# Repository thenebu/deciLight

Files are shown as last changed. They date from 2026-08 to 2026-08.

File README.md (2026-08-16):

🇩🇪 [Deutsch](#deutsch) | 🇬🇧 [English](#english)

## Deutsch

# noiselight 🚦

Ein Echtzeit-Lärmmonitor, der den Geräuschpegel als Ampel mit RGB-LEDs anzeigt.

> ✅ **Status:** Alle unten beschriebenen Funktionen wurden auf echter Hardware getestet,
> einschließlich der Home Assistant / MQTT-Discovery-Integration und des
> browserbasierten OTA-Updates (inkl. Neustart in die neu geflashte Firmware, mehrfach
> über einen Stromzyklus hinweg bestätigt).

<details>
<summary><strong>Inhaltsverzeichnis</strong></summary>

- [📋 Funktionen](#de-funktionen)
- [🛒 Verwendete Hardware](#de-verwendete-hardware)
- [💻 Kompatible Hardware](#de-kompatible-hardware)
- [🔧 Hardware-Einrichtung](#de-hardware-einrichtung)
- [🖨️ Gehäuse (3D-Druck)](#de-gehaeuse)
- [📊 Funktionsweise](#de-funktionsweise)
- [🎚️ Konfiguration](#de-konfiguration)
- [🌐 WiFi- und Web-Konfiguration](#de-wifi-web-konfiguration)
- [🏠 MQTT- / Home-Assistant-Integration](#de-mqtt-ha)
- [🔑 Passwörter](#de-passwoerter)
- [📡 OTA-Updates (Over-the-Air)](#de-ota)
- [🚀 Bauen und Hochladen](#de-bauen-hochladen)
- [📈 Serielle Ausgabe](#de-serielle-ausgabe)
- [🔧 Kalibrierung](#de-kalibrierung)
- [🔴 Fehlerbehebung](#de-fehlerbehebung)
- [📚 Referenzen](#de-referenzen)
- [📝 Lizenz](#de-lizenz)

</details>

## 📋 Funktionen

- **Echtzeit-Geräuscherkennung** über ein I2S-MEMS-Mikrofon
- **3-farbige Ampelanzeige**:
  - 🟢 **GRÜN** – Geräusch ist leise (unter dem Schwellenwert)
  - 🟡 **GELB** – Geräusch ist moderat (im mittleren Bereich)
  - 🔴 **ROT** – Geräusch ist laut (über dem Schwellenwert)
- **7er-NeoPixel-RGB-LED-Streifen** für helle, gut sichtbare Rückmeldung
- **A-bewertete Schallpegelmessung** (dBA) für eine realistische Wahrnehmung
- **Konfigurierbare Schwellenwerte** über persistenten Speicher
- **WiFi-Client-Modus** mit automatischem AP-Fallback für die Ersteinrichtung
- **Babyphone-Modus** – warmes, dimmbares Nachtlicht am Gerät, während ein anhaltend
  lauter Pegel (Auslöseschwelle + Halte-/Löschzeit mit Hysterese) einen Alarm
  ausschließlich per MQTT an Home Assistant meldet; die LED selbst bleibt ruhig
- **Live-Hören** – 16-kHz-PCM-Audiostream direkt im Browser, eigener TCP-Port, eigenes
  Passwort, mit Auto-Gain, damit auch leise Geräusche hörbar sind
- **MQTT- / Home-Assistant-Integration** mit MQTT-Discovery
- **Over-the-Air (OTA) Firmware-Updates**, sobald das Gerät mit dem Heimnetzwerk verbunden ist — per PlatformIO/ArduinoOTA **oder** direkt per Datei-Upload im Web-UI, ganz ohne Entwicklungsumgebung
- **Konfigurations-Export/Import** zum Sichern oder Klonen der Geräteeinstellungen
- **5-Minuten-Verlaufsdiagramm** im Web-UI
- **Firmware-Version** sichtbar im Web-UI-Footer und über MQTT (Diagnose-Topic mit Uptime, freiem Speicher, WLAN-Signalstärke, IP-Adresse und letztem Reset-Grund)
- **"Letzter Alarm"-Zeitstempel** über MQTT (Home-Assistant-Timestamp-Entity, zeigt automatisch "vor X Minuten" an)
- **Zwei getrennte Passwörter** – eins fürs Firmware-Flashen, eins fürs Live-Hören, damit
  das Weitergeben des einen nicht das andere mit verschenkt

## 🛒 Verwendete Hardware

Diese Teile habe ich selbst gekauft (Amazon.de, Stand: wie unten verlinkt):

| Komponente | Preis | Hinweis | Link |
|---|---|---|---|
| LED | 18€ (5er-Pack, 3,60€/Stk.) | WS2812 RGB-LED-Ring, 7×5050 mit integrierten Treibern | [Amazon](https://www.amazon.de/dp/B09K57Y9FL?ref=ppx_yo2ov_dt_b_fed_asin_title) |
| Board | 20€ (2er-Pack, 10,00€/Stk.) | Waveshare ESP32-S3 Mini Development Board | [Amazon](https://www.amazon.de/dp/B0CSK8B4GS?ref=ppx_yo2ov_dt_b_fed_asin_title) |
| Mikrofon | 9€ (3er-Pack, 3,00€/Stk.) | INMP441 omnidirektionales Mikrofonmodul, 24-Bit I2S | [Amazon](https://www.amazon.de/dp/B0DX1VMRK1?ref_=ppx_hzsearch_conn_dt_b_fed_asin_title_2) |

Grobe Gesamtkosten für **ein** komplettes Gerät (je ein LED-Ring + Board + Mikrofon):
3,60€ + 10€ + 3€ ≈ **16,60€ pro Gerät**.

Da alle drei Teile im Mehrfach-Pack verkauft werden, lassen sich mit den übrigen Teilen
mehrere weitere Geräte bauen, ohne viel mehr als für ein einzelnes zu bezahlen. Preise
und Verfügbarkeit entsprechen dem Stand, als die Links hinzugefügt wurden, und können
sich ändern. Die Links sind normale Amazon-Links (kein Affiliate-Tracking durch dieses
Projekt) — einfach das, was ich selbst gekauft habe.

## 💻 Kompatible Hardware

Dieses Projekt ist auf **ESP32** zugeschnitten — nicht auf ESP8266 oder andere
Mikrocontroller. Es nutzt ESP32-spezifische Peripherie (I2S für das Mikrofon, RMT für
die WS2812-LEDs) sowie FreeRTOS-Multitasking über zwei Kerne. Mindestanforderungen an
ein Ersatz-/Alternativboard:

- **Chip:** ESP32 (Xtensa- oder RISC-V-Varianten wie S3/C3) mit I2S- und
  RMT-Peripherie. Getestet auf **ESP32-S3**; andere ESP32-Varianten mit passender
  Pinbelegung sollten ebenfalls funktionieren, sind aber ungetestet.
- **Flash:** mindestens **4 MB**. Die OTA-Partitionstabelle (`default.csv`) braucht
  zwei App-Partitionen à ~1,25 MB für abwechselndes Flashen — die aktuelle Firmware
  belegt davon bereits ~86 % einer Partition, kleinere Flash-Größen reichen nicht.
- **RAM:** die üblichen ~320 KB internes SRAM eines ESP32(-S3) reichen locker (aktuell
  ~31 % Auslastung zur Laufzeit); **PSRAM wird nicht benötigt**.
- **WLAN:** 2,4-GHz-WiFi (Pflicht für Web-UI, MQTT und OTA).
- **USB:** Natives USB-CDC (wie beim ESP32-S3) vereinfacht Flashen und seriellen
  Monitor erheblich, ist aber kein Hard-Requirement — ein Board mit klassischer
  USB-UART-Brücke funktioniert auch, dann greift aber die Log-Umleitung in
  `include/config.h` nicht (die ist speziell für Boards ohne UART-Brücke gedacht,
  siehe Kommentar dort).

**Nicht kompatibel:** ESP8266 (kein I2S/RMT, kein FreeRTOS-Multicore, andere
Partitionierung) sowie generische AVR-/STM32-Boards ohne ESP-IDF-Unterstützung.

## 🔧 Hardware-Einrichtung

### Pin-Konfiguration

| Komponente | Pin | Farbe | Beschreibung |
|---|-----|---|---|
| **WS2812 LED-Daten** | GPIO 1 | - | NeoPixel-Streifen (7 LEDs) |
| **I2S L/R Select** | GPIO 3 | Grün | Mikrofon-Kanalauswahl (HIGH = RECHTER Kanal) |
| **I2S Word Select** | GPIO 4 | Blau | Mikrofon L/R-Takt |
| **I2S Serial Clock** | GPIO 5 | Weiß | Mikrofon-Bittakt |
| **I2S Serial Data** | GPIO 2 | Gelb | Mikrofon-Audiodaten |
| **Modus-Taster** | GPIO 6 | - | Taster gegen GND (interner Pull-up, aktiv LOW) |
| **Stromversorgung (5V)** | 5V | - | USB-Netzteil |
| **GND** | GND | - | Masse |

### Modus-Taster

Ein optionaler Taster an GPIO 6 (gegen GND) erlaubt Bedienung ohne WebUI:

- **Kurzer Druck**: schaltet den Anzeigemodus weiter (Ampel → VU-Meter → Babyphone →
  Einfarbig → Ampel …)
- **Langer Druck (gehalten, >600 ms)**: rampt die LED-Helligkeit hoch/runter; an den
  Grenzen (0/255) dreht die Richtung automatisch um (Ping-Pong). Beim Loslassen wird
  der erreichte Wert dauerhaft gespeichert.

Ist kein Taster angeschlossen, bleibt GPIO 6 dank internem Pull-up dauerhaft HIGH und
es passiert nichts - die Funktion ist also optional und stört ohne Hardware nicht.

## 🖨️ Gehäuse (3D-Druck)

Die 3D-Druckdateien liegen in [`3dprinting/`](./3dprinting) (Fusion-360-Quelldatei
sowie fertige `.3mf`-Projekte für Base, Cover, Visor, LED-Mount, ESP-Mount, Standfüße,
Linse und Reflektor). Details zu Druckprofilen findest du in
[`3dprinting/README.md`](./3dprinting/README.md).

In der Praxis gedruckt: die **Linse** in **PETG, transluzent**, damit das Licht schön
diffus streut - der Rest des Gehäuses (Base, Cover, Visor, LED-Mount, ESP-Mount,
Standfüße) in **PLA**. Das weicht vom in `3dprinting/README.md` hinterlegten
Bambu-Studio-Profil ab (dort ist z. B. PETG/TPU für die übrigen Teile vorgesehen) -
PLA hat sich für den Innenausbau als völlig ausreichend erwiesen, da das Gehäuse keiner
Wärme- oder mechanischen Belastung ausgesetzt ist.

## 📊 Funktionsweise

### Audio-Verarbeitungspipeline

1. **I2S-Abtastung** (48 kHz, 32-Bit)
   - Erfasst kontinuierlich Audio vom Mikrofon
   - Hochpräzise digitale Abtastung

2. **IIR-Filterung**
   - **Equalizer-Filter** (INMP441): Glättet den Frequenzgang des Mikrofons
   - **A-Bewertungsfilter**: Bildet die Empfindlichkeit des menschlichen Ohrs nach
     (betont mittlere Frequenzen)

3. **Schallpegelberechnung**
   - Wandelt gefilterte Samples in dB (Dezibel) um
   - Nutzt die Mikrofonkalibrierung aus `MIC_REF_DB`/`MIC_SENSITIVITY`
   - **Messfenster: 125 ms** (`SAMPLES_SHORT` = 6000 Samples bei 48 kHz). Das ist
     exakt die Zeitbewertung **"FAST" nach IEC 61672**, die auch jeder handelsübliche
     Schallpegelmesser verwendet — deshalb ist der Wert nicht frei wählbar, ohne die
     Kalibrierung zu entwerten
   - Gelesen wird allerdings in **zwei 62,5-ms-Halbblöcken** (`SAMPLES_CHUNK`), deren
     Quadratsummen addiert werden, bevor ein Messwert entsteht. Die IIR-Filter tragen
     ihren Zustand über den Aufruf hinaus, das Ergebnis ist also bitgleich zu einem
     durchgehenden 125-ms-Block — halbiert aber den Sample-Puffer von 24 KB auf 12 KB
   - Anschließend exponentielle Glättung (α = 0,3 pro Fenster, Zeitkonstante ≈ 350 ms)

4. **Entscheidungslogik**
   ```
   if (dB < db_normal_switchover)      → GRÜN   (ruhig)
   if (dB < db_warning_switchover)     → GELB   (laut)
   sonst                               → ROT    (zu laut)
   ```

## 🎚️ Konfiguration

### Standardwerte

Alle in `include/config.h`, zur Laufzeit über das Web-UI änderbar und im NVS persistent:

```cpp
DB_FLOOR                   37.0   // Grundpegel (unteres Ende der VU-Skala)
DB_NORMAL_SWITCHOVER       50.0   // darunter GRÜN, darüber GELB
DB_WARNING_SWITCHOVER      65.0   // darunter GELB, darüber ROT
LED_BRIGHTNESS               25   // 0-255
DISPLAY_MODE                  1   // 0=Ampel, 1=VU-Meter, 2=Babyphone

BABYPHONE_TRIGGER_DB       65.0   // Schwelle, die anhaltend überschritten werden muss
BABYPHONE_SUSTAIN_MS       5000   // so lange darüber → Alarm
BABYPHONE_CLEAR_MS         3000   // so lange darunter → Alarm gelöscht
BABYPHONE_NIGHT_COLOR  0xFF3C00   // warmes Bernstein, fast ohne Blauanteil
BABYPHONE_NIGHT_BRIGHTNESS   15   // 0-255, gedimmt
```

### Empfohlene Einstellungen

| Umgebung | Grün→Gelb | Gelb→Rot | Hinweise |
|---|---|---|---|
| Bibliothek/Ruhig | 30 | 50 | Sehr leise Räume |
| Klassenzimmer | 40 | 60 | Normaler Unterricht |
| Aktives Klassenzimmer | 45 | 70 | Gruppenarbeitsphasen |
| Werkstatt | 60 | 80 | Toleriert Maschinenlärm |
| Kinderzimmer (Babyphone) | 45 | 65 | Auslöseschwelle separat einstellen |

### Wissenschaftliche Grundlage der Standardwerte

Die Werkseinstellungen (Grün→Gelb bei **50 dB**, Gelb→Rot bei **65 dB**) sind keine
Zufallszahlen, sondern orientieren sich an anerkannten Lärmwirkungs-Richtwerten:

- **50 dB (Grün→Gelb):** Die WHO nennt in den *Guidelines for Community Noise* (1999,
  Tabelle 4.1) 50 dB LAeq als Richtwert, ab dem in Wohn-/Aufenthaltsräumen mit
  **moderater Belästigung** zu rechnen ist ("outdoor living area", moderate annoyance).
  Oberhalb dieses Pegels beginnt Lärm subjektiv als störend wahrgenommen zu werden.
- **65 dB (Gelb→Rot):** Normale Unterhaltungssprache liegt laut NIDCD/CDC-Referenztabellen
  bei etwa 60–70 dB(A) (1 m Abstand). Die WHO-Richtlinie weist darauf hin, dass oberhalb
  eines Hintergrundpegels von rund 65 dB die Sprachverständlichkeit deutlich leidet und
  die Stimme angehoben werden muss, während gleichzeitig laut Tabelle 4.1 die Schwelle zur
  **ernsten Belästigung** ("serious annoyance") erreicht wird.
- Zum Einordnen: **Gehörschäden** durch Dauerlärm sind erst bei deutlich höheren Pegeln
  relevant — NIOSH empfiehlt max. 85 dB(A) über 8 Std. (REL), OSHA erlaubt gesetzlich
  max. 90 dB(A) über 8 Std. (PEL). ROT markiert hier also eine **Komfort-/Konzentrations-
  Warnschwelle**, nicht bereits eine Gehörschäden-Warnung — dafür liegen die Pegel weit
  genug auseinander, dass ROT als früher, harmloser Hinweis taugt.
- Für spezielle Umgebungen (Klassenzimmer, Kinderzimmer) empfiehlt die WHO strengere
  Innenraum-Richtwerte (z. B. 35 dB LAeq in Klassenzimmern zur Sprachverständlichkeit,
  30 dB LAeq nachts im Schlafzimmer) — diese liegen jedoch so nah am technischen
  Grundrauschen des Mikrofons (`DB_FLOOR` ≈ 37 dB), dass eine LED-Ampel bei diesen engen
  Werten kaum noch sinnvoll zwischen "Grün" und "Gelb" unterscheiden könnte. Die
  Empfehlungen in der Tabelle oben sind deshalb praxisnah nach oben verschobene
  Näherungswerte, keine 1:1-Übernahme der WHO-Innenraumwerte.

**Quellen:**
- WHO (1999): [*Guidelines for Community Noise*](https://www.who.int/publications/i/item/a68672), Tabelle 4.1 (Richtwerte für spezifische Umgebungen)
- WHO Regional Office for Europe (2018): [*Environmental Noise Guidelines for the European Region*](https://cdn.who.int/media/docs/default-source/who-compendium-on-health-and-environment/who_compendium_noise_01042022.pdf)
- NIOSH: [*Criteria for a Recommended Standard – Occupational Noise Exposure*](https://www.nonoise.org/hearing/criteria/criteria.htm) (REL 85 dB(A)/8h)
- OSHA: [*Occupational Noise Exposure*](https://www.osha.gov/noise) (PEL 90 dB(A)/8h)

## 🌐 WiFi- und Web-Konfiguration

### WiFi-Modi

Das Gerät verbindet sich mit deinem Heimnetzwerk als **WiFi-Client (STA)**. Falls beim
Start noch kein Netzwerk konfiguriert ist oder das konfigurierte Netzwerk nicht
erreichbar ist, fällt es auf seinen eigenen **Access Point (AP)** zurück, sodass du das
Web-UI immer erreichen kannst:

- **SSID (Netzwerkname):** `noiselight`
- **Passwort:** `12345678`
- **IP-Adresse:** `192.168.4.1`
- **Port:** `80` (HTTP)

Sobald das Gerät mit dem Heimnetzwerk verbunden ist, ist es außerdem per mDNS unter
**`http://noiselight.local`** erreichbar.

### Erststart-WiFi über .env (optional)

Falls dein Smartphone/Laptop den `noiselight`-AP nicht sehen oder nicht beitreten kann,
oder du diesen Schritt lieber ganz überspringen möchtest, kopiere `.env.example` nach
`.env` (in .gitignore, wird nie committet) und trage deine Heim-WiFi-Zugangsdaten ein:

```bash
cp .env.example .env
# edit .env: WIFI_SSID=..., WIFI_PASSWORD=...
platformio run -t upload -e esp32-s3-devkitc1-n4r2
```

`load_env.py` bettet diese Werte als NVS-Standard ein, den ein frisch geflashtes Gerät
bei seinem allerersten Start verwendet — das ist nur relevant, bis die WiFi-Einstellungen
des Geräts einmal über das Web-UI gespeichert wurden (oder bereits aus einem früheren
Flash-Vorgang im NVS vorhanden sind); danach gewinnt immer der im NVS gespeicherte Wert
gegenüber dem `.env`-Standard.

### Einrichtungsschritte

1. **Erstverbindung (AP-Fallback):**
   - Öffne die WiFi-Einstellungen deines Geräts (Smartphone, Tablet, Laptop)
   - Wähle das Netzwerk `noiselight`
   - Gib das Passwort ein: `12345678`

2. **Konfigurationsseite öffnen:**
   - Öffne einen Browser und gehe zu: `http://192.168.4.1`
   - Das Web-Interface lädt automatisch

3. **Heim-WiFi beitreten:**
   - Trage SSID/Passwort deines Netzwerks im Bereich **Network** des Web-UI ein und
     speichere
   - Das Gerät verbindet sich mit deinen Zugangsdaten neu; bei Erfolg beendet es den AP
     und ist fortan unter `http://noiselight.local` (oder seiner neuen DHCP-Adresse)
     erreichbar
   - Schlägt die Verbindung fehl, fällt das Gerät wieder in den AP-Modus zurück, sodass
     du nie ausgesperrt wirst

4. **Einstellungen in Echtzeit konfigurieren:**
   - Live-dB-Pegelanzeige aktualisiert sich alle 200 ms
   - Alle Schieberegler aktualisieren die Vorschau sofort
   - Drücke **Save Configuration**, um die Einstellungen im Gerätespeicher zu sichern

### Web-Interface-Funktionen

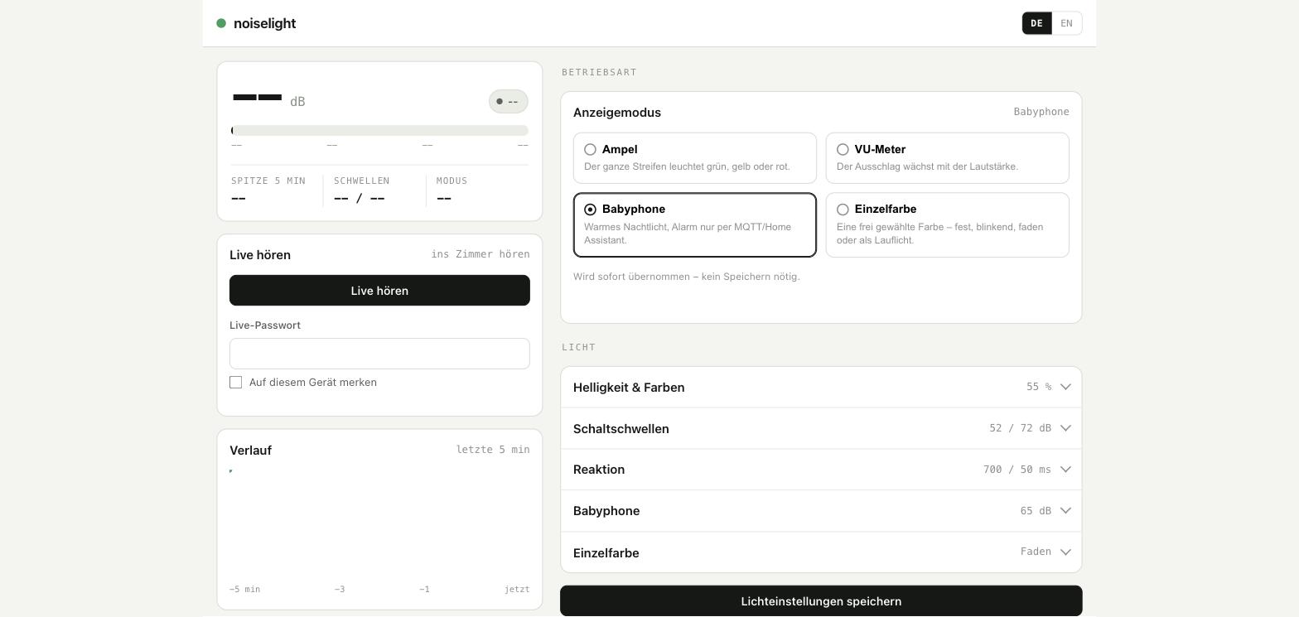
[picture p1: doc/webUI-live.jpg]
noiselight Web Interface – Live-Pegel, Betriebsart und Lichteinstellungen

*Live-dB-Anzeige, Verlaufsgraph und Betriebsart-Auswahl (Ampel / VU-Meter / Babyphone / Einzelfarbe)*

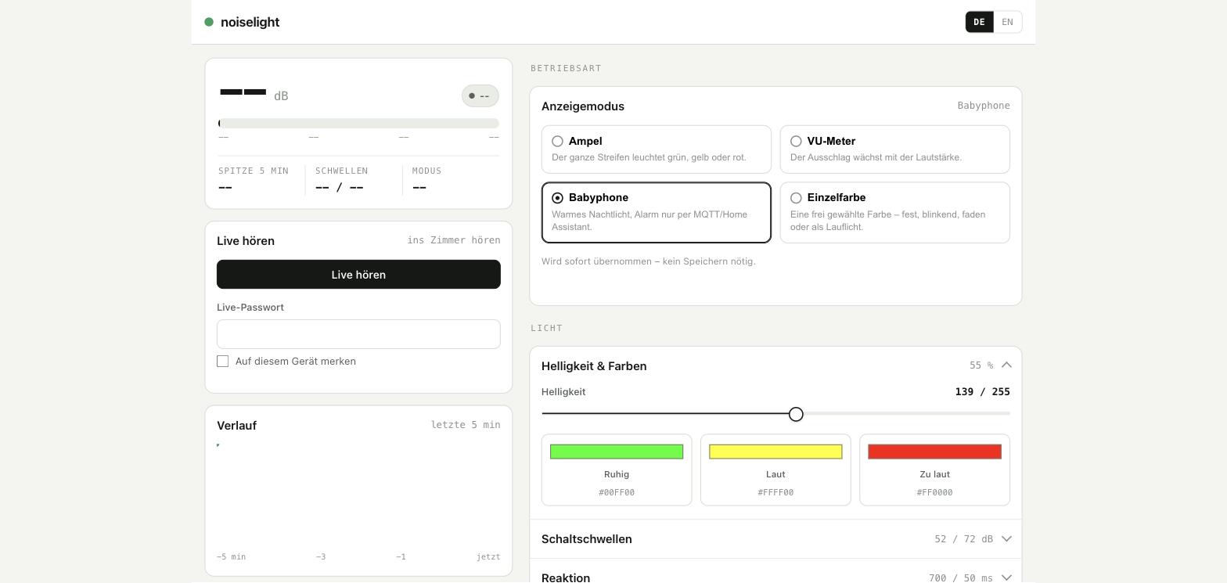
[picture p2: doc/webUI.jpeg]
noiselight Web Interface – Helligkeit & Farben

*Ausgeklappte Lichteinstellungen: Helligkeit sowie Farben für Ruhig/Laut/Zu laut*

**Anzeigemodus**
- **Ampel:** Alle LEDs zeigen eine einzelne Farbe (GRÜN/GELB/ROT)
- **VU-Meter:** LEDs bilden einen Verlaufsbalken, der die Geräuschintensität zeigt
- **Babyphone:** Der Streifen ist ein statisches, warmes Nachtlicht und reagiert
  bewusst *nicht* auf Geräusche. Der Alarm läuft ausschließlich über MQTT — die
  Beleuchtung im Kinderzimmer soll nicht blinken, wenn das Kind weint

**Live hören**
- Eigene Karte direkt unter der Pegelanzeige, in **jedem** Anzeigemodus verfügbar
- Streamt 16-kHz-PCM-Mono über einen eigenen TCP-Port (8081, `AUDIO_STREAM_PORT`) und
  spielt es über die Web-Audio-API im Browser ab
- Geschützt durch `LIVE_PASSWORD` — nicht durch das OTA-Passwort (siehe
  **Passwörter** weiter unten). Optional per Häkchen im Browser merkbar
- Ein Auto-Gain skaliert jeden Block auf einen Zielpegel (Attack sofort, Release
  verzögert), weil das Mikrofon für *Messgenauigkeit* kalibriert ist und ein leises
  Wimmern sonst kaum hörbar wäre
- Jeweils nur ein Zuhörer gleichzeitig; ein zweiter Verbindungsversuch wird mit
  "503 stream busy" abgewiesen. Der Ringpuffer wird erst beim Verbinden alloziert
  und beim Trennen wieder freigegeben

**LED-Einstellungen**
- **Helligkeit:** 0–255 (Standard: 25)
- **Farbauswahl:** Individuelle Farben für jede Lärmstufe wählen

**Umschaltpunkte (dB)**
- **Grundpegel:** Geräusch-Grundpegel (Standard: 37 dB)
- **Grün→Gelb:** Übergangsschwelle (Standard: 50 dB)
- **Gelb→Rot:** Alarmschwelle (Standard: 65 dB)
- **Farbvorschau:** Visueller Balken zeigt LED-Farben über den dB-Bereich

**Reaktionszeiten**
- **Nachleuchten:** Wie lange die aktuelle Farbe gehalten wird, nachdem der Ton
  aufgehört hat (0–3000 ms, Standard: 1500 ms)
- **Ansprechzeit:** Minimales Aktualisierungsintervall zwischen LED-Wechseln
  (0–500 ms, Standard: 100 ms). Gilt für Ampel *und* VU-Meter; letzteres hat
  zusätzlich eine harte Untergrenze von 20 ms, weil ein WS2812-Streifen darüber
  hinaus ohnehin nicht sinnvoll aktualisiert werden kann

**Babyphone-Einstellungen**
- **Auslöseschwelle** (dB), **Anhaltend für** (s) und **Löscht nach** (s) bilden einen
  Zustandsautomaten mit asymmetrischer Hysterese: der Alarm feuert erst nach einer
  ununterbrochen lauten Phase und löscht sich erst nach einer ununterbrochen leisen —
  ein kurzes Luftholen zwischen zwei Schreien setzt also nichts zurück
- **Nachtlicht-Farbe** und **-Helligkeit** für den Streifen in diesem Modus

**Verlaufsdiagramm**
- Live-Liniendiagramm der letzten 5 Minuten der dB-Messwerte (1 Sample/Sek.), bereitgestellt
  über `/api/history`

**Tagesstatistik (tägliche Zeitverteilung)**
- Gestapeltes Balkendiagramm, das zeigt, wie viel Zeit jeder Stunde (heute, 24 Buckets)
  in welchem Farbzustand (NORMAL/WARNING/ALERT) verbracht wurde, bereitgestellt über
  `/api/hourly`
- Setzt sich automatisch um Mitternacht (Ortszeit) zurück; ein **Zurücksetzen**-Button
  löscht sie auch manuell über `/api/hourly/reset`
- Erfordert, dass die Uhr des Geräts zuerst per NTP synchronisiert wurde (siehe
  **Zeitzone** unten) — bis dahin zeigt das Diagramm einen Hinweis statt Daten
- Die Einteilung in Buckets basiert auf der rohen (nicht gedämpften) Geräuschklassifizierung
  bei jedem Loop-Tick — derselben Klassifizierung, die MQTT als "level"-Sensor
  veröffentlicht — und nicht auf der anzeigegeglätteten Farbe, die ruhige Phasen
  unterbewerten würde

**Zeitzone**
- Der Bereich **Network** enthält ein Feld **Zeitzone (POSIX TZ)**, z. B.
  `CET-1CEST,M3.5.0,M10.5.0/3` (Europe/Berlin, Standard) oder `EST5EDT,M3.2.0,M11.1.0`
  (US-Ostküste) — wird direkt an die `configTzTime()`-Funktion des ESP32 übergeben,
  sodass die Stunden-Buckets der Tagesstatistik mit deiner lokalen Uhrzeit
  übereinstimmen, inklusive Sommerzeitumstellung
- Anders als ein fester UTC-Offset kodiert ein POSIX-TZ-String auch, *wann* sich die
  Uhr verschiebt (der Teil `M3.5.0,M10.5.0/3`), sodass Sommer-/Winterzeit automatisch
  gehandhabt wird — keine manuelle Anpassung zweimal im Jahr nötig
- Erfordert eine Internetverbindung (NTP-Sync gegen `pool.ntp.org`/`time.nist.gov`);
  greift nicht im AP-Fallback-Modus ohne Internetzugang

### Persistenter Speicher

Alle Konfigurationsänderungen werden automatisch im **NVS (Non-Volatile Storage)** des
ESP32 gespeichert:
- Einstellungen überstehen einen Stromausfall
- Werden beim Gerätestart automatisch geladen
- Konfiguration erreichbar über `/api/config`, WiFi-/MQTT-Einstellungen über
  `/api/network`

### Konfigurations-Export/Import

Das Web-UI kann die gesamte Gerätekonfiguration (LED-/Schwellenwert-Einstellungen
**und** WiFi-/MQTT-Zugangsdaten) als JSON-Datei über `/api/config/export` exportieren
und über `/api/config/import` auf einem anderen Gerät (oder nach einem Reset)
wiederherstellen. Praktisch, um eine funktionierende Einrichtung zu sichern oder auf
ein zweites Gerät zu klonen.

> ⚠️ Die exportierte Datei enthält deine WiFi- und MQTT-Passwörter im Klartext —
> behandle sie wie jede andere Zugangsdatendatei.

## 🏠 MQTT- / Home-Assistant-Integration

Sobald das Gerät mit dem Heimnetzwerk verbunden ist, kann es seine Lärmmesswerte an
einen MQTT-Broker senden und sich selbst über MQTT-Discovery bei **Home Assistant**
anmelden — keine manuelle Entitätskonfiguration nötig.

### Einrichtung

1. Trage im Bereich **Network** des Web-UI Host/Port deines MQTT-Brokers ein sowie,
   falls erforderlich, Benutzername/Passwort, und speichere.
2. Das Gerät verbindet sich automatisch und meldet sich per Discovery unter
   `homeassistant/<component>/<device-id>/...` an. Auf dem schnellen State-Topic
   (alle ~2 Sekunden, `noiselight/<device-id>/state`):
   - **Noise Level** – der aktuelle dB-Messwert, auf eine ganze Zahl gerundet
   - **Noise Level Status** – `normal` / `warning` / `alert`
   - **Anzeigemodus** – `traffic_light` / `vu_meter` / `babyphone`
   - **Babyphone Alarm** – `binary_sensor` (`device_class: sound`), spiegelt den
     Zustandsautomaten aus dem Babyphone-Modus. Bewusst auf dem 2-Sekunden-Topic und
     nicht bei der Diagnose, damit ein Alarm schnell in HA ankommt
3. Ein Verfügbarkeits-Topic (`.../availability`) sorgt dafür, dass Home Assistant das
   Gerät als offline markiert, wenn die Verbindung abbricht.
4. Ein Diagnose-Topic (`noiselight/<device-id>/debug`, alle 60 Sekunden) liefert als
   eigene "diagnostic"-Entitäten:
   - **Firmware Version**, **Uptime**, **WiFi Signal**, **IP Address**,
     **Last Reset Reason**
   - **Free Heap** – Summe *aller* freien Bytes
   - **Largest Free Block** – größter *zusammenhängender* Block. Zusammen mit Free Heap
     auf einer Karte macht das Fragmentierung sichtbar: bleibt Free Heap flach, während
     dieser Wert über Tage absackt, stanzt irgendwo eine malloc/free-Schleife Löcher in
     den Heap
   - **Letzter Alarm (Rot)** – Zeitstempel-Sensor, der automatisch anzeigt, wie lange
     der letzte Alarm-Zustand her ist

Die Geräte-ID wird aus den letzten 6 Hex-Ziffern der MAC-Adresse abgeleitet (z. B.
`noiselight-a1b2c3`).

## 🔑 Passwörter

Die Firmware kennt **zwei getrennte Zugangsdaten** (beide in `include/config.h`):

| Define | Standard | Schützt |
|---|---|---|
| `OTA_PASSWORD` | `changeme-ota` | ArduinoOTA (Flashen per PlatformIO/IDE) **und** `POST /update` im Web-UI |
| `LIVE_PASSWORD` | `changeme-live` | Live-Hören auf Port 8081 (`/listen`) |

Dazu `OTA_USERNAME` und `LIVE_USERNAME` (beide `admin`) für die HTTP-Basic-Auth der
zwei Endpunkte; ArduinoOTA selbst prüft nur das Passwort.

Warum getrennt: Firmware flashen kann das Gerät unbrauchbar machen und sollte bei dem
bleiben, der es wartet. Ins Zimmer hören ist dagegen eine Alltagshandlung für alle im
Haushalt — und die, die man um drei Uhr nachts halbwach auf dem Handy eintippt. Das
Live-Passwort weiterzugeben darf nicht bedeuten, das Recht zum Neuflashen mitzuverschenken.

> ⚠️ **Beide Standardwerte vor dem Einsatz im Heimnetz ändern.** Sie stehen im Klartext
> in diesem öffentlichen Repository.

Nur das Live-Passwort lässt sich im Browser per Häkchen "Auf diesem Gerät merken"
speichern (`localStorage`, im Klartext, gebunden an die Adresse des Geräts). Für das
OTA-Passwort gibt es diese Option bewusst nicht.

> **Hinweis:** Das Web-UI baut seine `Authorization`-Header in JavaScript, und dieser
> Code ist ein String-Literal in `src/web.cpp` — er sieht die `#define`s nicht. Die
> *Benutzernamen* stehen dort ein zweites Mal. Änderst du einen davon, musst du ihn an
> beiden Stellen ändern.

## 📡 OTA-Updates (Over-the-Air)

Sobald das Gerät mit deinem Heimnetzwerk verbunden ist (STA-Modus), kann die Firmware
statt per USB über WiFi aktualisiert werden — mit der dedizierten
`esp32-s3-devkitc1-n4r2-ota`-PlatformIO-Umgebung:

```bash
platformio run -t upload -e esp32-s3-devkitc1-n4r2-ota
```

Dies lädt auf `noiselight.local` hoch und benötigt das in `include/config.h`
konfigurierte OTA-Passwort (`OTA_PASSWORD`, muss mit `upload_flags` in
`platformio.ini` übereinstimmen). **Ändere das Standardpasswort, bevor du das Gerät in
deinem Heimnetzwerk einsetzt** — sonst kann jeder im selben Netzwerk einen
OTA-Flash-Versuch starten. OTA ist erst nach einer erfolgreichen WiFi-STA-Verbindung
aktiviert; im AP-Fallback-Modus ist es nie erreichbar.

> **Toolchain-Hinweis:** `platformio.ini` pinnt die `espressif32`-Platform auf den
> [pioarduino](https://github.com/pioarduino/platform-espressif32)-Fork (Arduino-ESP32
> 3.3.11 / ESP-IDF 5.5.5) — bewusst dieselbe Core-Generation wie die Arduino-IDE-
> Installation. Der ESP32-S3-Bootloader hat App-Rollback aktiviert: ein per OTA
> geschriebenes Image muss vom selben Core-Generation stammen wie der Bootloader,
> sonst validiert das Image nicht und der Bootloader fällt beim nächsten Neustart
> stillschweigend auf die alte Partition zurück, ohne die neue Firmware auch nur
> einmal zu starten. Mit gepinntem `pioarduino` und einer Selbstbestätigung beim Boot
> (`esp_ota_mark_app_valid_cancel_rollback()` in `src/main.cpp`, sobald die laufende
> Partition auf "pending verify" steht) funktioniert OTA jetzt zuverlässig — mehrfach
> über einen echten Stromzyklus hinweg getestet.

**Browserbasiertes Hochladen:** Das WebUI hat außerdem einen eigenen Bereich
"Firmware-Update" zum direkten Hochladen einer `.bin`-Datei aus einem Browser-Tab,
ohne PlatformIO oder Arduino IDE. Der `/update`-Endpoint ist per HTTP Basic Auth
geschützt — Benutzername `admin` (`OTA_USERNAME`), Passwort `OTA_PASSWORD` (beide in
`include/config.h`). Trägst du im WebUI-Passwortfeld das richtige `OTA_PASSWORD` ein,
läuft der Upload direkt durch; rufst du `/update` ohne diese Zugangsdaten auf (oder ist
das Feld leer/falsch), fragt stattdessen der Browser selbst mit einem Login-Popup nach
Benutzername/Passwort. Fertige Binärdateien für diesen Weg liegen im Verzeichnis
[`firmware/`](firmware/) — eine `.bin` pro `FIRMWARE_VERSION`, automatisch von jedem
`pio run` gebaut.

## 🚀 Bauen und Hochladen

### Voraussetzungen

- PlatformIO (VS-Code-Erweiterung oder CLI)
- Arduino IDE (optional, für direkte Kompilierung)

### Build

```bash
# Using PlatformIO
platformio run -e esp32-s3-devkitc1-n4r2

# Or in VS Code: Ctrl+Shift+B → Build
```

### Upload

```bash
# Using PlatformIO (USB)
platformio run -t upload -e esp32-s3-devkitc1-n4r2

# Or over WiFi, once on your home network (see OTA section above)
platformio run -t upload -e esp32-s3-devkitc1-n4r2-ota

# Or in VS Code: Ctrl+Shift+B → Upload
```

## 📈 Serielle Ausgabe

Das Gerät gibt dB-Messwerte über den seriellen Monitor aus (115200 Baud):

```
Leq: 45.3 dB | Min: 40 | Max: 60 | GREEN
Leq: 62.1 dB | Min: 40 | Max: 60 | RED
Leq: 55.2 dB | Min: 40 | Max: 60 | YELLOW
```

## 🔧 Kalibrierung

### Mikrofonempfindlichkeit

Wenn die Messwerte durchgehend abweichen:

1. **Bekannten Schallpegel messen** (z. B. mit einer Smartphone-App)
2. **Mit der seriellen Ausgabe vergleichen**
3. **MIC_OFFSET_DB in `main.cpp` anpassen:**
   ```cpp
   #define MIC_OFFSET_DB 3.0103  // Increase/decrease calibration offset
   ```

## 🔴 Fehlerbehebung

| Problem | Ursache | Lösung |
|---|---|---|
| Immer GRÜN | Mikrofon nicht angeschlossen | I2S-Pins prüfen (GPIO 3, 5, 2) |
| Immer ROT | Kalibrierung falsch | MIC_OFFSET_DB anpassen |
| Keine serielle Ausgabe | Falsche Baudrate | Auf 115200 einstellen |
| Keine LED-Reaktion | Falscher LED-Pin | GPIO-1-Verbindung prüfen |
| Hoher Grundgeräuschpegel des Mikrofons | Elektrisches Rauschen | Datenleitungen abschirmen, Stromversorgung prüfen |
| Gerät bleibt am `noiselight`-AP hängen | Heim-WiFi nicht erreichbar/falsches Passwort | Zugangsdaten im Web-UI prüfen oder erneut mit dem AP verbinden und neu eingeben |
| MQTT-Entitäten erscheinen nicht in Home Assistant | Broker nicht erreichbar oder Discovery noch nicht gesendet | Host/Port/Zugangsdaten in den Netzwerkeinstellungen prüfen; Discovery wird bei jeder Neuverbindung erneut gesendet |
| OTA-Upload schlägt fehl/läuft in Timeout | Gerät im AP-Fallback oder falsches `--auth`-Passwort | Sicherstellen, dass das Gerät im Heimnetzwerk ist (`noiselight.local` löst auf) und `OTA_PASSWORD` mit `platformio.ini` übereinstimmt |

## 📚 Referenzen

- **Original deciLight Project**: https://github.com/bbbenji/deciLight
- **FastLED Documentation**: http://fastled.io/
- **ESP-IDF I2S API**: https://docs.espressif.com/projects/esp-idf/en/latest/esp32/api-reference/peripherals/i2s.html
- **A-weighting Filter**: https://en.wikipedia.org/wiki/A-weighting
- **PubSubClient (MQTT)**: https://github.com/knolleary/pubsubclient
- **Home Assistant MQTT Discovery**: https://www.home-assistant.io/integrations/mqtt/#mqtt-discovery

## 📝 Lizenz

Dieses Projekt startete als Fork von [deciLight](https://github.com/bbbenji/deciLight) (GPL-3.0).
Die Grundidee (ESP32 + I2S-Mikrofon + NeoPixel-Lichtsäule) und die I2S-Audio-Basis stammen von dort;
Web-UI, Netzwerk-Stack (WiFi STA/AP-Fallback, mDNS), MQTT/Home-Assistant-Integration und die
Audio-Pipeline wurden seitdem vollständig neu geschrieben. Lizenziert unter der GNU General Public
License v3.0.

---

## English

# noiselight 🚦

A real-time noise monitor that displays sound levels as a traffic light using RGB LEDs.

> ✅ **Status:** All features below have been tested on real hardware, including the
> Home Assistant / MQTT discovery integration and the browser-based OTA update
> (including rebooting into the newly flashed firmware, confirmed across a real power
> cycle, more than once).

<details>
<summary><strong>Table of Contents</strong></summary>

- [📋 Features](#en-features)
- [🛒 Hardware Used](#en-hardware-used)
- [💻 Compatible Hardware](#en-compatible-hardware)
- [🔧 Hardware Setup](#en-hardware-setup)
- [🖨️ Enclosure (3D Printing)](#en-enclosure)
- [📊 How It Works](#en-how-it-works)
- [🎚️ Configuration](#en-configuration)
- [🌐 WiFi & Web Configuration](#en-wifi-web-configuration)
- [🏠 MQTT / Home Assistant Integration](#en-mqtt-ha)
- [🔑 Passwords](#en-passwords)
- [📡 OTA (Over-the-Air) Updates](#en-ota)
- [🚀 Building & Uploading](#en-building-uploading)
- [📈 Serial Output](#en-serial-output)
- [🔧 Calibration](#en-calibration)
- [🔴 Troubleshooting](#en-troubleshooting)
- [📚 References](#en-references)
- [📝 License](#en-license)

</details>

## 📋 Features

- **Real-time noise detection** via I2S MEMS microphone
- **3-color traffic light display**:
  - 🟢 **GREEN** – Noise is low (quieter than threshold)
  - 🟡 **YELLOW** – Noise is moderate (within range)
  - 🔴 **RED** – Noise is high (exceeded threshold)
- **7 NeoPixel RGB LED strip** for bright, visible feedback
- **A-weighted sound level measurement** (dBA) for realistic perception
- **Configurable thresholds** via persistent storage
- **WiFi client mode** with automatic AP fallback for first-time setup
- **Babyphone mode** – a warm, dimmable night light on the device while a sustained
  loud level (trigger threshold plus hold/clear times with hysteresis) raises an alarm
  over MQTT to Home Assistant only; the LED itself stays calm
- **Live listening** – 16 kHz PCM audio stream straight in the browser, on its own TCP
  port with its own password, auto-gained so quiet sounds are audible too
- **MQTT / Home Assistant integration** with MQTT discovery
- **Over-the-air (OTA) firmware updates** once connected to your home network — via PlatformIO/ArduinoOTA **or** a direct file upload in the web UI, no dev tooling required
- **Config export/import** for backing up or cloning device settings
- **5-minute history graph** in the web UI
- **Firmware version** visible in the web UI footer and over MQTT (a diagnostics topic with uptime, free heap, WiFi signal strength, IP address, and last reset reason)
- **"Last alert" timestamp** over MQTT (a Home Assistant timestamp entity that automatically renders "X minutes ago")
- **Two separate passwords** – one for flashing firmware, one for live listening, so
  handing out the one does not give away the other

## 🛒 Hardware Used

This is the exact parts list I actually bought (Amazon.de, as of when the links below
were added):

| Component | Price | Note | Link |
|---|---|---|---|
| LED | €18 (5-pack, €3.60/unit) | WS2812 RGB LED ring, 7×5050 with integrated drivers | [Amazon](https://www.amazon.de/dp/B09K57Y9FL?ref=ppx_yo2ov_dt_b_fed_asin_title) |
| Board | €20 (2-pack, €10.00/unit) | Waveshare ESP32-S3 Mini Development Board | [Amazon](https://www.amazon.de/dp/B0CSK8B4GS?ref=ppx_yo2ov_dt_b_fed_asin_title) |
| Microphone | €9 (3-pack, €3.00/unit) | INMP441 omnidirectional microphone module, 24-bit I2S | [Amazon](https://www.amazon.de/dp/B0DX1VMRK1?ref_=ppx_hzsearch_conn_dt_b_fed_asin_title_2) |

Rough total cost for **one** complete device (one LED ring + one board + one
microphone): €3.60 + €10 + €3 ≈ **€16.60 per unit**.

Since all three parts come in multi-packs, the leftover parts let you build several
more devices for not much more than the cost of one. Prices and availability are as of
when these links were added and may change. These are plain Amazon links (not
affiliate-tracked by this project) — just what I bought.

## 💻 Compatible Hardware

This project is built for **ESP32** — not ESP8266 or other microcontrollers. It uses
ESP32-specific peripherals (I2S for the microphone, RMT for the WS2812 LEDs) and
FreeRTOS multitasking across two cores. Minimum requirements for a
replacement/alternative board:

- **Chip:** ESP32 (Xtensa or RISC-V variants such as S3/C3) with I2S and RMT
  peripherals. Tested on **ESP32-S3**; other ESP32 variants with a matching pinout
  should also work but are untested.
- **Flash:** at least **4 MB**. The OTA partition table (`default.csv`) needs two
  ~1.25 MB app partitions for A/B flashing — current firmware already uses ~86% of
  one partition, so smaller flash sizes won't fit.
- **RAM:** the usual ~320 KB of internal SRAM on an ESP32(-S3) is plenty (~31% runtime
  usage currently); **PSRAM is not required**.
- **WiFi:** 2.4 GHz WiFi (required for the web UI, MQTT, and OTA).
- **USB:** Native USB-CDC (like the ESP32-S3) makes flashing and serial monitoring
  much simpler, but isn't a hard requirement — a board with a classic USB-UART bridge
  chip also works, though the log redirection in `include/config.h` won't kick in
  (that's specifically for boards without a UART bridge, see the comment there).

**Not compatible:** ESP8266 (no I2S/RMT, no FreeRTOS multicore, different
partitioning) or generic AVR/STM32 boards without ESP-IDF support.

## 🔧 Hardware Setup

### Pin Configuration

| Component | Pin | Color | Description |
|---|-----|---|---|
| **WS2812 LED Data** | GPIO 1 | - | NeoPixel strip (7 LEDs) |
| **I2S L/R Select** | GPIO 3 | Green | Microphone channel select (set HIGH = RIGHT channel) |
| **I2S Word Select** | GPIO 4 | Blue | Microphone L/R clock |
| **I2S Serial Clock** | GPIO 5 | White | Microphone bit clock |
| **I2S Serial Data** | GPIO 2 | Yellow | Microphone audio data |
| **Mode button** | GPIO 6 | - | Button to GND (internal pull-up, active LOW) |
| **Power (5V)** | 5V | - | USB power supply |
| **GND** | GND | - | Ground |

### Mode Button

An optional button on GPIO 6 (to GND) allows control without the WebUI:

- **Short press**: advances the display mode (Traffic Light → VU Meter → Babyphone →
  Solid Color → Traffic Light …)
- **Long press (held, >600ms)**: ramps LED brightness up/down; at the bounds (0/255)
  the direction automatically flips (ping-pong). Releasing persists the reached value.

Without a button wired up, GPIO 6 stays HIGH via the internal pull-up and nothing
happens - the feature is optional and inert without the hardware.

## 🖨️ Enclosure (3D Printing)

The 3D print files live in [`3dprinting/`](./3dprinting) (a Fusion 360 source file plus
ready-to-slice `.3mf` projects for base, cover, visor, LED mount, ESP mount, feet, lens,
and reflector). See [`3dprinting/README.md`](./3dprinting/README.md) for print profile
details.

What was actually printed: the **lens** in **translucent PETG** for a nicely diffused
light, and the rest of the enclosure (base, cover, visor, LED mount, ESP mount, feet) in
**PLA**. That differs from the Bambu Studio profile documented in
`3dprinting/README.md` (which specifies PETG/TPU for the other parts) - PLA turned out
to be plenty for an indoor enclosure with no heat or mechanical load.

## 📊 How It Works

### Audio Processing Pipeline

1. **I2S Sampling** (48 kHz, 32-bit)
   - Captures continuous audio from the microphone
   - High-precision digital sampling

2. **IIR Filtering**
   - **Equalizer filter** (INMP441): Flattens microphone frequency response
   - **A-weighting filter**: Mimics human ear sensitivity (emphasizes mid-frequencies)

3. **Sound Level Calculation**
   - Converts filtered samples to dB (decibels)
   - Uses the microphone calibration from `MIC_REF_DB`/`MIC_SENSITIVITY`
   - **Measurement window: 125 ms** (`SAMPLES_SHORT` = 6000 samples at 48 kHz). That is
     exactly the **"FAST" time weighting defined by IEC 61672**, which every commercial
     sound level meter uses — so it is not a free parameter without invalidating the
     calibration
   - It is *read*, however, in **two 62.5 ms half blocks** (`SAMPLES_CHUNK`) whose sums
     of squares are accumulated before a measurement is emitted. The IIR filters carry
     their state across calls, so the result is bit-for-bit identical to one continuous
     125 ms block — while halving the sample buffer from 24 KB to 12 KB
   - Then exponential smoothing (α = 0.3 per window, time constant ≈ 350 ms)

4. **Decision Logic**
   ```
   if (dB < db_normal_switchover)      → GREEN   (quiet)
   if (dB < db_warning_switchover)     → YELLOW  (loud)
   else                                → RED     (too loud)
   ```

## 🎚️ Configuration

### Defaults

All in `include/config.h`, changeable at runtime through the web UI and persisted in NVS:

```cpp
DB_FLOOR                   37.0   // floor level (bottom of the VU scale)
DB_NORMAL_SWITCHOVER       50.0   // below GREEN, above YELLOW
DB_WARNING_SWITCHOVER      65.0   // below YELLOW, above RED
LED_BRIGHTNESS               25   // 0-255
DISPLAY_MODE                  1   // 0=traffic light, 1=VU meter, 2=babyphone

BABYPHONE_TRIGGER_DB       65.0   // threshold that must be exceeded continuously
BABYPHONE_SUSTAIN_MS       5000   // that long above it → alarm
BABYPHONE_CLEAR_MS         3000   // that long below it → alarm cleared
BABYPHONE_NIGHT_COLOR  0xFF3C00   // warm amber, almost no blue
BABYPHONE_NIGHT_BRIGHTNESS   15   // 0-255, dimmed
```

### Recommended Settings

| Environment | Green→Yellow | Yellow→Red | Notes |
|---|---|---|---|
| Library/Silent | 30 | 50 | Very quiet spaces |
| Classroom | 40 | 60 | Normal teaching |
| Active classroom | 45 | 70 | Group work sessions |
| Workshop | 60 | 80 | Tolerate machinery |
| Nursery (babyphone) | 45 | 65 | Set the trigger threshold separately |

### Scientific Basis for the Defaults

The factory defaults (Green→Yellow at **50 dB**, Yellow→Red at **65 dB**) aren't arbitrary —
they're anchored to established noise-effect guideline values:

- **50 dB (Green→Yellow):** The WHO's *Guidelines for Community Noise* (1999, Table 4.1)
  lists 50 dB LAeq as the guideline value at which **moderate annoyance** begins in
  outdoor/living areas. Above this level, noise starts being subjectively perceived as
  disruptive.
- **65 dB (Yellow→Red):** Normal conversational speech runs roughly 60–70 dB(A) at 1 m per
  NIDCD/CDC reference charts. The WHO guidelines note that speech intelligibility degrades
  markedly and speakers must raise their voice once background noise exceeds about 65 dB,
  and Table 4.1 also places the onset of **serious annoyance** around this level.
- For context: **hearing damage** from sustained noise only becomes relevant at
  meaningfully higher levels — NIOSH recommends a max. of 85 dB(A) over 8h (REL), OSHA's
  legal limit is 90 dB(A) over 8h (PEL). RED here is a **comfort/concentration warning
  threshold**, not a hearing-damage warning — the gap between 65 dB and the occupational
  limits is deliberately wide enough that RED still functions as an early, low-stakes cue.
- For specialized settings (classrooms, nurseries), the WHO recommends stricter indoor
  guideline values (e.g. 35 dB LAeq in classrooms for speech intelligibility, 30 dB LAeq
  at night in bedrooms) — but those sit close enough to the microphone's own noise floor
  (`DB_FLOOR` ≈ 37 dB) that an LED indicator could barely distinguish "green" from "yellow"
  at those levels. The recommendations in the table above are therefore practical
  approximations nudged upward, not a direct copy of WHO's indoor values.

**Sources:**
- WHO (1999): [*Guidelines for Community Noise*](https://www.who.int/publications/i/item/a68672), Table 4.1 (guideline values for specific environments)
- WHO Regional Office for Europe (2018): [*Environmental Noise Guidelines for the European Region*](https://cdn.who.int/media/docs/default-source/who-compendium-on-health-and-environment/who_compendium_noise_01042022.pdf)
- NIOSH: [*Criteria for a Recommended Standard – Occupational Noise Exposure*](https://www.nonoise.org/hearing/criteria/criteria.htm) (REL 85 dB(A)/8h)
- OSHA: [*Occupational Noise Exposure*](https://www.osha.gov/noise) (PEL 90 dB(A)/8h)

## 🌐 WiFi & Web Configuration

### WiFi Modes

The device connects to your home network as a **WiFi client (STA)**. If no network is
configured yet, or the configured network can't be reached at boot, it falls back to
its own **Access Point (AP)** so you can always reach the web UI:

- **SSID (Network Name):** `noiselight`
- **Password:** `12345678`
- **IP Address:** `192.168.4.1`
- **Port:** `80` (HTTP)

Once connected to your home network, the device is also reachable via mDNS at
**`http://noiselight.local`**.

### First-Boot WiFi via .env (optional)

If your phone/laptop can't see or join the `noiselight` AP, or you'd rather skip that
step entirely, copy `.env.example` to `.env` (gitignored, never committed) and fill in
your home WiFi credentials:

```bash
cp .env.example .env
# edit .env: WIFI_SSID=..., WIFI_PASSWORD=...
platformio run -t upload -e esp32-s3-devkitc1-n4r2
```

`load_env.py` bakes these in as the NVS default a freshly flashed device tries on its
very first boot — it only matters until the device's WiFi settings are saved once via
the web UI (or already exist in NVS from a previous flash), at which point the
NVS-stored value always wins over the `.env` default.

### Setup Instructions

1. **First-time connection (AP fallback):**
   - Open your device's WiFi settings (phone, tablet, laptop)
   - Select network `noiselight`
   - Enter password: `12345678`

2. **Open the configuration page:**
   - Open browser and go to: `http://192.168.4.1`
   - The web interface will load automatically

3. **Join your home WiFi:**
   - Enter your network's SSID/password in the **Network** section of the web UI and save
   - The device reconnects using your credentials; if successful, it drops the AP and is
     reachable at `http://noiselight.local` (or its new DHCP address) going forward
   - If the connection fails, the device falls back to AP mode again so you're never locked out

4. **Configure settings in real-time:**
   - Live dB level display updates every 200ms
   - All sliders update preview instantly
   - Press **Save Configuration** to persist settings to device storage

### Web Interface Features

noiselight Web Interface – live level, operating mode and light settings
*Live dB reading, history graph, and operating mode picker (traffic light / VU meter / babyphone / single color)*

noiselight Web Interface – brightness & colours
*Expanded light settings: brightness and quiet/loud/too-loud colours*

**Display Mode**
- **Traffic Light:** All LEDs show single color (GREEN/YELLOW/RED)
- **VU Meter:** LEDs create gradient bar showing sound intensity
- **Babyphone:** The strip is a static, warm night light and deliberately does *not*
  react to sound. The alarm goes out over MQTT only — the light in a child's room
  should not start flashing because the child is crying

**Live Listening**
- Its own card right below the level readout, available in **every** display mode
- Streams 16 kHz mono PCM over a dedicated TCP port (8081, `AUDIO_STREAM_PORT`) and
  plays it back through the browser's Web Audio API
- Guarded by `LIVE_PASSWORD` — not the OTA password (see **Passwords** below).
  Optionally remembered in the browser via a checkbox
- An auto-gain scales each block to a target level (instant attack, delayed release),
  because the microphone is calibrated for *measurement accuracy* and a quiet whimper
  would otherwise be barely audible
- One listener at a time; a second connection attempt is rejected with "503 stream
  busy". The ring buffer is allocated on connect and released on disconnect

**LED Settings**
- **Brightness:** 0–255 (default: 25)
- **Color Selection:** Choose custom colors for each noise level

**Switchover Points (dB)**
- **Floor Level:** Noise floor baseline (default: 37 dB)
- **Green→Yellow:** Transition threshold (default: 50 dB)
- **Yellow→Red:** Alert threshold (default: 65 dB)
- **Color Preview:** Visual bar shows LED colors across dB range

**Response Timing**
- **Decay Time:** How long to hold current color after sound stops (0–3000 ms, default: 1500 ms)
- **Response Time:** Minimum update interval between LED changes (0–500 ms, default: 100 ms).
  Applies to traffic light *and* VU meter; the latter additionally has a hard 20 ms floor,
  since a WS2812 strip cannot usefully be refreshed faster than that anyway

**Babyphone Settings**
- **Trigger level** (dB), **Sustained for** (s) and **Clears after** (s) form a state
  machine with asymmetric hysteresis: the alarm only fires after an uninterrupted loud
  phase and only clears after an uninterrupted quiet one — so a breath between two
  cries resets nothing
- **Night light colour** and **brightness** for the strip in this mode

**History Graph**
- Live line chart of the last 5 minutes of dB readings (1 sample/sec), served from `/api/history`

**Tagesstatistik (Daily Time Distribution)**
- Stacked bar chart showing how much of each hour (today, 24 buckets) was spent in each
  color state (NORMAL/WARNING/ALERT), served from `/api/hourly`
- Auto-resets at local midnight; a **Zurücksetzen** (Reset) button also clears it manually
  via `/api/hourly/reset`
- Needs the device's clock to be synced via NTP first (see **Time Zone** below) — until
  then the chart shows a note instead of data
- Bucketing uses the raw (non-decayed) noise classification each loop tick, the same
  classification MQTT publishes as its "level" sensor — not the display-smoothed color,
  which would understate quiet periods

**Time Zone**
- The **Network** section has a **Zeitzone (POSIX TZ)** field, e.g.
  `CET-1CEST,M3.5.0,M10.5.0/3` (Europe/Berlin, the default) or `EST5EDT,M3.2.0,M11.1.0`
  (US Eastern) — passed straight to the ESP32's `configTzTime()`, so the Tagesstatistik
  hour buckets line up with your local wall clock, DST transitions included
- Unlike a fixed UTC offset, a POSIX TZ string encodes *when* the clock shifts (the
  `M3.5.0,M10.5.0/3` part), so summer/winter time is handled automatically — no manual
  adjustment twice a year
- Requires an internet connection (NTP sync against `pool.ntp.org`/`time.nist.gov`); doesn't
  apply while running in AP-fallback mode with no internet access

### Persistent Storage

All configuration changes are automatically saved to ESP32's **NVS (Non-Volatile Storage)**:
- Settings survive power loss
- Load automatically on device startup
- Config accessible via `/api/config`, WiFi/MQTT settings via `/api/network`

### Config Export/Import

The web UI can export the full device configuration (LED/threshold settings **and**
WiFi/MQTT credentials) as a JSON file via `/api/config/export`, and restore it on
another device (or after a reset) via `/api/config/import`. Handy for backing up a
working setup or cloning it to a second unit.

> ⚠️ The exported file contains your WiFi and MQTT passwords in plain text — store it
> like any other credential file.

## 🏠 MQTT / Home Assistant Integration

Once connected to your home network, the device can publish its noise readings to an
MQTT broker and announce itself to **Home Assistant** via MQTT discovery — no manual
entity configuration needed.

### Setup

1. In the web UI's **Network** section, enter your MQTT broker's host/port and,
   if required, username/password, then save.
2. The device connects automatically and announces itself via discovery on
   `homeassistant/<component>/<device-id>/...`. On the fast state topic (every ~2
   seconds, `noiselight/<device-id>/state`):
   - **Noise Level** – the current dB reading, rounded to a whole number
   - **Noise Level Status** – `normal` / `warning` / `alert`
   - **Anzeigemodus** – `traffic_light` / `vu_meter` / `babyphone`
   - **Babyphone Alarm** – a `binary_sensor` (`device_class: sound`) mirroring the
     babyphone state machine. Deliberately on the 2-second topic rather than with the
     diagnostics, so an alarm reaches HA quickly
3. An availability topic (`.../availability`) makes Home Assistant mark the device
   offline if the connection drops.
4. A diagnostics topic (`noiselight/<device-id>/debug`, every 60 seconds) publishes,
   each as its own "diagnostic" entity:
   - **Firmware Version**, **Uptime**, **WiFi Signal**, **IP Address**,
     **Last Reset Reason**
   - **Free Heap** – the sum of *all* free bytes
   - **Largest Free Block** – the largest *contiguous* one. Charted together with Free
     Heap this makes fragmentation visible: if Free Heap stays flat while this one sinks
     over days, some malloc/free loop is punching holes in the heap
   - **Letzter Alarm (Rot)** – timestamp sensor that automatically shows how long ago
     the last alert state was

The device ID is derived from the last 6 hex digits of its MAC address (e.g.
`noiselight-a1b2c3`).

## 🔑 Passwords

The firmware uses **two separate credentials** (both in `include/config.h`):

| Define | Default | Guards |
|---|---|---|
| `OTA_PASSWORD` | `changeme-ota` | ArduinoOTA (flashing from PlatformIO/IDE) **and** `POST /update` in the web UI |
| `LIVE_PASSWORD` | `changeme-live` | Live listening on port 8081 (`/listen`) |

Plus `OTA_USERNAME` and `LIVE_USERNAME` (both `admin`) for the two endpoints' HTTP
Basic Auth; ArduinoOTA itself only checks the password.

Why they are separate: flashing firmware can brick the device and should stay with
whoever maintains it. Listening to the room is an everyday action for everyone in the
household — and the one you type half asleep on a phone at 3am. Sharing the live
password must not also hand out the ability to reflash the device.

> ⚠️ **Change both defaults before deploying on your home network.** They are in
> plain text in this public repository.

Only the live password can be remembered in the browser, via the "Remember on this
device" checkbox (`localStorage`, in the clear, scoped to the device's address). The
OTA password deliberately has no such option.

> **Note:** The web UI builds its `Authorization` headers in JavaScript, and that code
> is a string literal inside `src/web.cpp` — it cannot see the `#define`s. The
> *usernames* are repeated there. If you change either, change it in both places.

## 📡 OTA (Over-the-Air) Updates

Once the device is connected to your home network (STA mode), firmware can be updated
over WiFi instead of USB, using the dedicated `esp32-s3-devkitc1-n4r2-ota` PlatformIO
environment:

```bash
platformio run -t upload -e esp32-s3-devkitc1-n4r2-ota
```

This uploads to `noiselight.local` and requires the OTA password configured in
`include/config.h` (`OTA_PASSWORD`, must match `upload_flags` in `platformio.ini`).
**Change the default password before deploying to your home network** — anyone on the
same network can otherwise attempt an OTA flash. OTA is only enabled after a successful
WiFi STA connection; it's never exposed while the device is on the AP fallback.

> **Toolchain note:** `platformio.ini` pins the `espressif32` platform to the
> [pioarduino](https://github.com/pioarduino/platform-espressif32) fork (Arduino-ESP32
> 3.3.11 / ESP-IDF 5.5.5) — deliberately the same core generation as the Arduino IDE
> install. The ESP32-S3 bootloader has app rollback enabled: an OTA-flashed image needs
> to come from the same core generation as the bootloader, or it fails to validate and
> the bootloader silently reverts to the old partition on the very next reset, without
> the new firmware ever running even once. With `pioarduino` pinned and a boot-time
> self-confirmation (`esp_ota_mark_app_valid_cancel_rollback()` in `src/main.cpp`,
> whenever the running partition is in "pending verify") OTA now works reliably —
> confirmed across a real power cycle, more than once.

**Browser-based upload:** the WebUI also has its own "Firmware-Update" section for
uploading a `.bin` directly from a browser tab, no PlatformIO or Arduino IDE required.
The `/update` endpoint is protected by HTTP Basic Auth — username `admin`
(`OTA_USERNAME`), password `OTA_PASSWORD` (both in `include/config.h`). Enter the
correct `OTA_PASSWORD` in the WebUI's password field and the upload goes through
directly; if you hit `/update` without those credentials (or the field is empty/wrong),
the browser itself pops up a native login prompt asking for username/password instead.
Ready-to-flash binaries for this path live in the [`firmware/`](firmware/) directory —
one `.bin` per `FIRMWARE_VERSION`, built automatically by every `pio run`.

## 🚀 Building & Uploading

### Prerequisites

- PlatformIO (VS Code extension or CLI)
- Arduino IDE (optional, for direct compilation)

### Build

```bash
# Using PlatformIO
platformio run -e esp32-s3-devkitc1-n4r2

# Or in VS Code: Ctrl+Shift+B → Build
```

### Upload

```bash
# Using PlatformIO (USB)
platformio run -t upload -e esp32-s3-devkitc1-n4r2

# Or over WiFi, once on your home network (see OTA section above)
platformio run -t upload -e esp32-s3-devkitc1-n4r2-ota

# Or in VS Code: Ctrl+Shift+B → Upload
```

## 📈 Serial Output

The device outputs dB measurements to the serial monitor (115200 baud):

```
Leq: 45.3 dB | Min: 40 | Max: 60 | GREEN
Leq: 62.1 dB | Min: 40 | Max: 60 | RED
Leq: 55.2 dB | Min: 40 | Max: 60 | YELLOW
```

## 🔧 Calibration

### Microphone Sensitivity

If readings are consistently off:

1. **Measure known sound level** (e.g., using phone app)
2. **Compare with serial output**
3. **Adjust MIC_OFFSET_DB** in `main.cpp`:
   ```cpp
   #define MIC_OFFSET_DB 3.0103  // Increase/decrease calibration offset
   ```

## 🔴 Troubleshooting

| Issue | Cause | Solution |
|---|---|---|
| Always GREEN | Microphone not connected | Check I2S pins (GPIO 3,5,2) |
| Always RED | Calibration off | Adjust MIC_OFFSET_DB |
| No serial output | Wrong baud rate | Set to 115200 |
| No LED response | Wrong LED pin | Verify GPIO 1 connection |
| Microphone noise floor high | Electrical noise | Shield data lines, check power supply |
| Device stuck on `noiselight` AP | Home WiFi unreachable/wrong password | Check credentials in the web UI, or reconnect to the AP and re-enter them |
| MQTT entities not appearing in Home Assistant | Broker unreachable or discovery not yet sent | Verify host/port/credentials in Network settings; discovery re-sends on every reconnect |
| OTA upload fails/times out | Device on AP fallback, or wrong `--auth` password | Confirm device is on your home network (`noiselight.local` resolves) and `OTA_PASSWORD` matches `platformio.ini` |

## 📚 References

- **Original deciLight Project**: https://github.com/bbbenji/deciLight
- **FastLED Documentation**: http://fastled.io/
- **ESP-IDF I2S API**: https://docs.espressif.com/projects/esp-idf/en/latest/esp32/api-reference/peripherals/i2s.html
- **A-weighting Filter**: https://en.wikipedia.org/wiki/A-weighting
- **PubSubClient (MQTT)**: https://github.com/knolleary/pubsubclient
- **Home Assistant MQTT Discovery**: https://www.home-assistant.io/integrations/mqtt/#mqtt-discovery

## 📝 License

This project started as a fork of [deciLight](https://github.com/bbbenji/deciLight) (GPL-3.0).
The core idea (ESP32 + I2S microphone + NeoPixel light column) and the I2S audio foundation come
from there; the web UI, network stack (WiFi STA/AP fallback, mDNS), MQTT/Home Assistant
integration, and audio pipeline have since been rewritten from scratch. Licensed under the GNU
General Public License v3.0.

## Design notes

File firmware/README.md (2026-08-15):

# Prebuilt firmware binaries

This directory holds ready-to-flash firmware binaries, one `.bin` file per
`FIRMWARE_VERSION` (see `include/config.h`). Each file is generated
automatically by `copy_firmware_bin.py` at the end of every `pio run`, for
both the USB and OTA build environments - don't hand-edit or hand-add
binaries here.

Because old versions are never overwritten (each build is named
`noiselight-<version>.bin`), any previously built version stays available for
re-flashing.

## Using a binary

1. Open the device's WebUI in a browser.
2. Go to the "Firmware-Update" section.
3. Select the desired `noiselight-<version>.bin` from this folder.
4. Enter the `OTA_PASSWORD` (from `include/config.h`).
5. Upload - the device reboots automatically on success.

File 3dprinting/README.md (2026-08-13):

# deciLight – 3D-Druckdateien

Dieser Ordner enthält die 3D-Modelle für das deciLight-Gehäuse.

- `deciLight.f3d` – Fusion 360 Quelldatei (alle Teile)
- `deciLight-main.3mf` – Gehäuse: Base, Cover, Visor, LED-Mount, ESP-Mount
- `deciLight-feet.3mf` – 4x Standfüße
- `deciLight-lens.3mf` – Diffusor-Linse
- `deciLight-reflector.3mf` – Reflektor

Die `.3mf`-Dateien enthalten bereits fertige Bambu-Studio-Projekte inkl.
Druckeinstellungen (Slicer: Bambu Studio, Drucker: Bambu Lab X1 Carbon,
0.4 mm Düse).

## Druckeinstellungen

Basisprofil: **0.20mm Standard @BBL X1C**

| Teil | Material | Layer Height | Wandlinien | Infill | Top/Bottom Layers | Düsentemp. | Bett-temp. | Brim |
|---|---|---|---|---|---|---|---|---|
| main (Base/Cover/Visor/LED-Mount/ESP-Mount) | PETG (Bambu PETG Basic), Farbe `#363636` | 0.20 mm | 2 | 15 % (Gyroid) | 5 / 3 | 255 °C | 70 °C | Auto, 5 mm |
| feet | TPU (Bambu TPU 95A) | 0.20 mm | 2 | 15 % (Grid) | Standard | 230 °C | 35 °C | Auto, 5 mm |
| lens | PETG (Bambu PETG Basic), Farbe `#FFFFFF`, für den Diffusor-Effekt ggf. transparentes/natur PETG verwenden | 0.20 mm | 2 | 15 % (Grid) | 5 / 3 | 255 °C | 70 °C | Auto, 5 mm |
| reflector | PETG (Bambu PETG Basic), Farbe `#363636` | 0.20 mm | 1 | 0 % (kein Infill) | 0 / 3 | 255 °C | 70 °C | Auto, 5 mm |

Weitere Einstellungen (für alle Teile gleich):
- Düsendurchmesser: 0.4 mm
- Supports: aus (`enable_support = 0`), Support-Winkel-Schwelle 30° falls doch benötigt
- Bett-Typ: Hot Plate (Textured/Engineering Plate empfohlen für PETG/TPU)

## Hinweise

- **feet** aus TPU drucken für rutschfeste, leicht flexible Standfüße.
- **reflector** hat bewusst keinen Top-Layer und keinen Infill (dünne
  Schale) – bei Bedarf innen mit reflektierender Folie/Farbe nachbehandeln.
- **lens** wurde als weißes PETG geslict; für einen echten Diffusor-Effekt
  transparentes oder natur-farbenes PETG (oder PETG-Diffusor-Filament)
  verwenden.
- Alle `.3mf`-Dateien lassen sich direkt in Bambu Studio (oder kompatiblen
  Slicern wie OrcaSlicer) öffnen – die Einstellungen sind bereits enthalten.

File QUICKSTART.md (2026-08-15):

# Quick Start Guide - noiselight 🚦

## 1️⃣ Hardware Checklist

- [ ] **ESP32-S3 DevKit** 
- [ ] **I2S MEMS Microphone** (INMP441 or INMP408)
- [ ] **WS2812 NeoPixel LED strip** (12x or more)
- [ ] **5V USB Power Supply** (2A minimum)
- [ ] **Micro USB cable** (programming)
- [ ] **Jumper wires** with proper gauge (AWG 22-24)

## 2️⃣ Wiring

### Microphone → ESP32

| Microphone | ESP32 | Wire Color |
|---|---|---|
| VDD (3.3V) | 3.3V | - |
| GND | GND | - |
| WS (L/R) | GPIO 4 | Green |
| SCK (BCLK) | GPIO 6 | White |
| SD (SDI) | GPIO 7 | Yellow |

### NeoPixel → ESP32

| LED Strip | ESP32 | Wire Color |
|---|---|---|
| 5V | 5V | Red |
| GND | GND | Black |
| DI (Data) | GPIO 2 | Green |

## 3️⃣ Software Setup

### Install PlatformIO (VS Code)

```bash
# In VS Code: 
# Ctrl+Shift+X → Search "platformio" → Install
```

### Build Project

```bash
# In terminal:
cd ~/Documents/PROJECTEN/noise-light/FW/esp32-noise-light
pio run -e esp32-s3-devkitc1-n4r2
```

### Upload to ESP32

```bash
pio run -t upload -e esp32-s3-devkitc1-n4r2
```

### Monitor Serial Output

```bash
pio device monitor -b 115200
```

## 4️⃣ Testing

### Power On
- LED strip should flash **black** on startup
- Serial monitor should show "NOISE TRAFFIC LIGHT STARTING"

### Test Microphone

Snap fingers near microphone:
- If working: dB value should jump in serial output
- Color should change: GREEN → YELLOW → RED

### Test Thresholds

**Default:**
- GREEN: < 40 dB
- YELLOW: 40-60 dB  
- RED: > 60 dB

**Try:**
1. Silent room → Should be GREEN
2. Normal talking → Should be YELLOW
3. Loud talking/clapping → Should be RED

## 5️⃣ Troubleshooting

### "error: Namespace 'i2s_mode_t' has no member named 'I2S_MODE_MASTER'"

**Fix:** Update ESP32 Arduino core:
```bash
pio update
```

### Microphone not detected

Check:
- [ ] Correct pins: GPIO 4 (WS), 6 (SCK), 7 (SD)
- [ ] Microphone powered (3.3V)
- [ ] Secure connections (no loose wires)
- [ ] Microphone polarity correct (VDD≠GND)

### LED not responding

Check:
- [ ] GPIO 2 connected to LED DI
- [ ] 5V power supplied to LEDs
- [ ] Correct LED count (12) in code
- [ ] Try adjusting brightness in code

### Serial garbage/no output

Set baud rate to **115200** in monitor settings.

## 6️⃣ Customization

### Change Thresholds

Edit `main.cpp`:
```cpp
int dB_min_default = 40;  // Change to 35, 45, etc.
int dB_max_default = 60;  // Change to 55, 70, etc.
```

### Change LED Count

Edit `main.cpp`:
```cpp
#define NUM_LEDS 12  // Change if your strip has different count
```

### Change Colors

Edit traffic light logic in `main.cpp`:
```cpp
if (Leq_dB < dB_min) {
  fill_solid(leds, NUM_LEDS, CRGB::Lime);    // Change GREEN
  Serial.println("QUIET");
}
```

Available colors: `Green`, `Red`, `Yellow`, `Blue`, `White`, `Orange`, `Cyan`, `Purple`, `Lime`, `Pink`

## 7️⃣ Calibration for Accuracy

### Measure Reference Noise

Use phone app (e.g., "Decibel Meter"):
1. Measure known sound level
2. Read dB value from serial monitor
3. Compare: expected vs actual

### Adjust Calibration

If off by ~5 dB, modify in `main.cpp`:
```cpp
#define MIC_OFFSET_DB 3.0103  // Increase or decrease
```

Example: If reading is 5 dB too low:
```cpp
#define MIC_OFFSET_DB 8.0103  // +5.0 offset
```

## 📚 Next Steps

- [ ] Test with different environments (classroom, workshop, etc.)
- [ ] Find optimal thresholds for your use case
- [ ] Create fixtures/enclosure for LED strip
- [ ] Add WiFi monitoring (future enhancement)
- [ ] Set up multiple units in classroom

## 🆘 Get Help

1. Check serial output for errors
2. Review README.md in project root
3. Check deciLight original: https://github.com/bbbenji/deciLight
4. ESP32 docs: https://docs.espressif.com/

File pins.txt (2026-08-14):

pins.txt
# Noise Traffic Light - Pin Configuration
# ==========================================
# ESP32-S3 DevKit v1.2 (N4 R2)

## RGB LED STRIP (WS2812 NeoPixel)
# ─────────────────────────────────
LED_DATA = GPIO 1  # NeoPixel Data In (7x WS2812)
LED_COUNT = 7      # Number of LEDs

## I2S MICROPHONE (INMP441 or compatible)
# ────────────────────────────────────────
MIC_LR  = GPIO 3   # L/R Select (Channel Select) - GREEN wire (HIGH=RIGHT)
MIC_WS  = GPIO 4   # Word Select (L/R Clock) - BLUE wire
MIC_SCK = GPIO 5   # Serial Clock (BCLK) - WHITE wire
MIC_SD  = GPIO 2   # Serial Data (SDO) - YELLOW wire

## REFERENCE (deciLight Original Pins - for comparison)
# ──────────────────────────────────────────────────────
# deciLight used: WS=15, SCK=14, SD=32, LED=2
# Our hardware: LR=3, WS=4, SCK=5, SD=2, LED=1

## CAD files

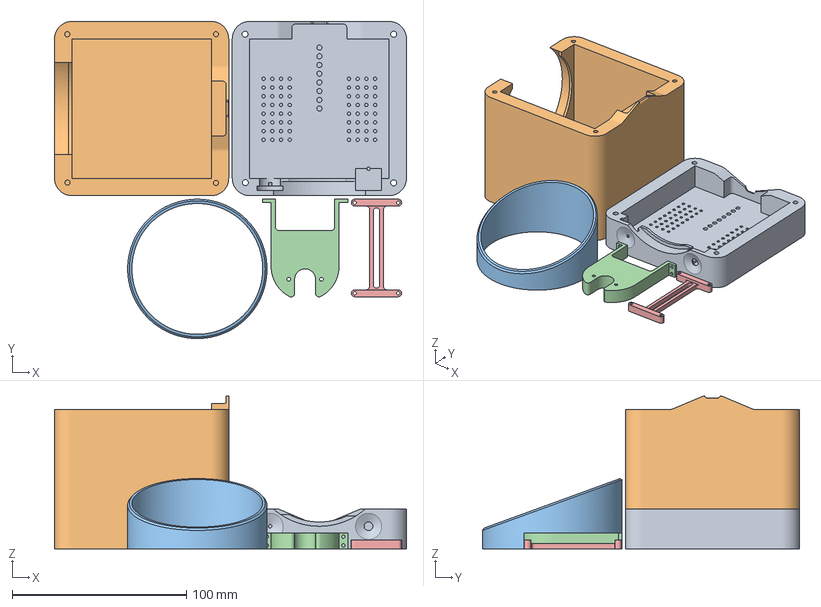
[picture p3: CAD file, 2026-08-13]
3dprinting/deciLight-main.3mf
202.0 x 182.0 x 87.8 mm
base.stl
cover.stl
visor.stl
led_mount.stl
esp_mount.stl

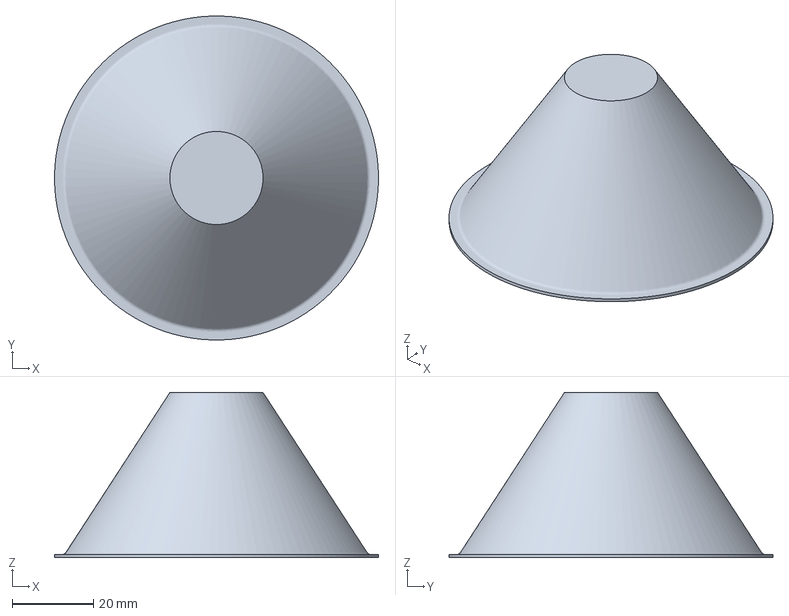
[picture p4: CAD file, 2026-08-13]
3dprinting/deciLight-reflector.3mf
80.0 x 80.0 x 40.8 mm

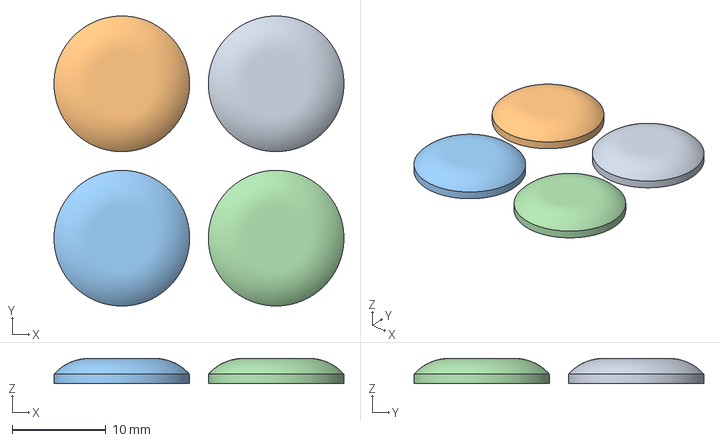
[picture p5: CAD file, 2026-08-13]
3dprinting/deciLight-feet.3mf
31.0 x 31.0 x 2.70 mm
foot.stl x 4

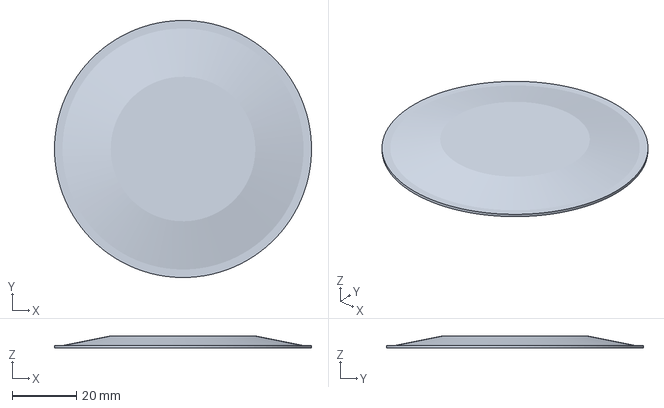
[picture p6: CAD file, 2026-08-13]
3dprinting/deciLight-lens.3mf
80.0 x 80.0 x 3.80 mm

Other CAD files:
3dprinting/deciLight.f3d

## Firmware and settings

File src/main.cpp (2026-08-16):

/*
 * NOISE TRAFFIC LIGHT
 * 
 * ESP32 Noise-based RGB Traffic Light
 * Adapted from deciLight by bbbenji
 * Original: https://github.com/bbbenji/deciLight
 * 
 * This monitors ambient sound level via I2S microphone and displays:
 * - GREEN: Noise is LOW (below threshold)
 * - YELLOW: Noise is MEDIUM (between thresholds)
 * - RED: Noise is HIGH (above threshold)
 * 
 * CLASS-BASED ARCHITECTURE:
 * - config.h: All configuration constants and #defines
 * - Microphone: I2S microphone and audio processing (includes reader task)
 * - LEDController: LED control and display modes (includes LED task)
 * - WebService: WiFi AP and web configuration interface (includes web task)
 * - main.cpp: Setup, instance creation, and task coordination
 */

#include <Arduino.h>
#include <esp_ota_ops.h>
#include "config.h"
#include "led.h"
#include "microphone.h"
#include "net_manager.h"
#include "mqtt.h"
#include "web.h"
#include "audio_stream.h"

//
// SETUP
//
void setup() {
  delay(100);
  Serial.begin(115200);
  Serial.setDebugOutput(true);
  delay(500);  // Extra delay for USB CDC to initialize
  
  Serial.println("\n\n--- BOOT START ---");
  
  log_e("\n=== NOISE TRAFFIC LIGHT STARTING ===");
  log_i("Firmware version: %s", FIRMWARE_VERSION);
  {
    // Diagnostic only - see the "still shows old FIRMWARE_VERSION after a
    // successful-looking OTA" investigation: which partition is actually
    // executing this boot, so it can be compared against the "target"
    // partition Update.begin() logs during the next OTA attempt.
    const esp_partition_t* running = esp_ota_get_running_partition();
    log_i("Running from partition: %s@0x%06x", running ? running->label : "?", running ? running->address : 0);
  }

  //
  // OTA ROLLBACK SELF-CONFIRMATION  (root cause of "OTA succeeds, reboot
  // shows the OLD firmware again")
  //
  // The bootloader flashed onto this board by the Arduino IDE (esp32 core
  // 3.x) is built with CONFIG_BOOTLOADER_APP_ROLLBACK_ENABLE=y. With that
  // option, esp_ota_set_boot_partition() - which Update.end(true) calls
  // internally - does NOT simply say "boot app1 from now on". It writes an
  // otadata entry pointing at app1 whose ota_state is ESP_OTA_IMG_NEW, i.e.
  // "boot app1 once, on probation". That is why the diagnostic readback of
  // esp_ota_get_boot_partition() right after Update.end() correctly reports
  // app1: otadata really does point there. But the state machine then runs:
  //
  //   reset #1: bootloader flips NEW -> PENDING_VERIFY and boots app1
  //   app1 must call esp_ota_mark_app_valid_cancel_rollback() to commit
  //   reset #2: if it never did, the bootloader marks app1 ABORTED and
  //             rolls back to app0 - the old firmware, exactly as observed
  //
  // Arduino core 3.x makes that call for you inside initArduino(), but the
  // block is guarded by #ifdef CONFIG_APP_ROLLBACK_ENABLE, and the ESP-IDF
  // that PlatformIO's esp32 core 2.0.5 ships does NOT define that symbol.
  // So every .bin in firmware/ (all PlatformIO builds) boots once from app1
  // on probation, never commits, and gets rolled back to app0 on the next
  // reset - which is why USB flashing always works (esptool rewrites
  // otadata at 0xe000 outright and never involves the rollback state
  // machine) while /update never once stuck.
  //
  // Doing it explicitly here, with no #ifdef, makes the firmware commit
  // itself regardless of which toolchain built it or how the bootloader on
  // the device is configured. On a device whose bootloader has rollback
  // disabled, the state is simply ESP_OTA_IMG_UNDEFINED and this is a
  // no-op.
  {
    const esp_partition_t* running = esp_ota_get_running_partition();
    esp_ota_img_states_t ota_state = ESP_OTA_IMG_UNDEFINED;
    if (running && esp_ota_get_state_partition(running, &ota_state) == ESP_OK) {
      log_i("[OTA] Running partition state: %d", (int)ota_state);
      if (ota_state == ESP_OTA_IMG_PENDING_VERIFY) {
        esp_err_t err = esp_ota_mark_app_valid_cancel_rollback();
        if (err == ESP_OK) {
          log_i("[OTA] Image was on rollback probation - marked valid, "
                "this firmware is now permanent");
        } else {
          log_e("[OTA] esp_ota_mark_app_valid_cancel_rollback() failed: %d", (int)err);
        }
      }
    } else {
      log_i("[OTA] Running partition has no otadata state (rollback not in use)");
    }
  }
  log_i("CPU: %d MHz, PSRAM: %d bytes", ESP.getCpuFreqMHz(), ESP.getFreePsram());

  // Initialize microphone (starts I2S reader task)
  microphone.init();

  // Auto-baseline: sample the ambient level for a few seconds right after
  // boot and average it into a suggested noise floor. Deliberately NOT
  // written into config.db_floor automatically - that would silently
  // override a saved user setting on every reboot. Instead it's exposed
  // as `suggested_floor` on /api/status, and the web UI offers it as a
  // one-click suggestion next to the existing "Current" button.
  {
    const uint32_t warmup_ms = 4000;
    const uint32_t sample_interval_ms = 200;
    double sum = 0.0;
    int samples = 0;
    uint32_t warmup_start = millis();
    log_i("[BOOT] Sampling ambient level for baseline suggestion (%dms)...", warmup_ms);
    while (millis() - warmup_start < warmup_ms) {
      sum += microphone.getLevel();
      samples++;
      delay(sample_interval_ms);
    }
    if (samples > 0) {
      double suggested = sum / samples;
      web_service.setSuggestedFloor(suggested);
      log_i("[BOOT] Suggested floor: %.1f dB (%d samples)", suggested, samples);
    }
  }

  // Mode button (GPIO 6, wired to GND) - internal pull-up, so idle reads
  // HIGH and a press pulls it LOW.
  pinMode(BUTTON_PIN, INPUT_PULLUP);

  // Initialize LED controller
  led_controller.init();

  // Initialize networking (WiFi STA with AP fallback, mDNS) before the web
  // server so the HTTP server comes up on whichever interface is active.
  network_service.init();

  // Initialize web service
  web_service.init();

  // Initialize MQTT (connection itself is deferred and driven from the web
  // task loop - see WebService::webTaskHandler())
  mqtt_service.init();

  // Initialize the live-listen audio stream service (Babyphone Phase 2) -
  // own dedicated task/port, independent of the WebService/WebTask above.
  audio_stream.init();

  // Start RTOS tasks
  web_service.startTask();
  audio_stream.startTask();

  log_e("=== SYSTEM READY ===\n");
}

//
// MAIN LOOP - Coordinator task
// Gets audio level from microphone and passes to LED controller
//
void loop() {
  // Get audio level from microphone
  double level_dB = microphone.getLevel();
  Config config = web_service.getConfigSnapshot();

  // Update LED display with current level and config
  led_controller.handleLevel(level_dB, config);

  // Update web interface with current level
  web_service.updateLevel(level_dB);

  //
  // MODE BUTTON (GPIO 6): short press = next display mode, long press
  // (held) = ramp led_brightness up/down, bouncing off 0/255. All state
  // here is static because this runs on the single main-loop task - no
  // locking needed, unlike the cross-core config access above.
  //
  {
    unsigned long now_ms = millis();

    static int last_raw_state = HIGH;
    static unsigned long last_edge_ms = 0;
    static bool button_down = false;         // debounced state
    static unsigned long press_start_ms = 0;
    static bool ramping = false;              // crossed into long-press this hold
    static bool ramp_up = true;               // persists across presses, flips at 0/255
    static unsigned long last_ramp_step_ms = 0;

    int raw = digitalRead(BUTTON_PIN);
    if (raw != last_raw_state) {
      last_edge_ms = now_ms;
      last_raw_state = raw;
    }

    if (now_ms - last_edge_ms > BUTTON_DEBOUNCE_MS) {
      bool pressed_now = (raw == LOW);
      if (pressed_now != button_down) {
        button_down = pressed_now;
        if (button_down) {
          // Just pressed
          press_start_ms = now_ms;
          ramping = false;
        } else {
          // Just released
          if (ramping) {
            web_service.persistConfig();  // ramp's final brightness -> NVS
          } else {
            web_service.cycleDisplayMode();
          }
        }
      }
    }

    if (button_down) {
      if (!ramping && (now_ms - press_start_ms >= BUTTON_LONG_PRESS_MS)) {
        ramping = true;
        last_ramp_step_ms = now_ms;
      }
      if (ramping && (now_ms - last_ramp_step_ms >= BUTTON_RAMP_INTERVAL_MS)) {
        last_ramp_step_ms = now_ms;
        int delta = ramp_up ? BUTTON_RAMP_STEP : -BUTTON_RAMP_STEP;
        uint8_t new_brightness = web_service.adjustLedBrightness(delta);
        // Hit a bound: flip direction so continuing to hold bounces back,
        // and the next press-and-hold picks up where this one left off.
        if (new_brightness == 255) ramp_up = false;
        else if (new_brightness == 0) ramp_up = true;
      }
    }
  }

  // The two statistics calls below are throttled rather than run on every
  // iteration: accumulateHourlyStat() calls time() + localtime_r() (not
  // cheap) and both work on elapsed-millisecond deltas, so a coarser tick
  // costs them no accuracy - the Babyphone sustain/clear windows are
  // measured in whole seconds. Unthrottled this ran thousands of times a
  // second for no benefit.
  static unsigned long last_stats_ms = 0;
  unsigned long now = millis();
  if (now - last_stats_ms >= 200) {
    last_stats_ms = now;

    // Track today's hour-of-day time distribution, using the same raw
    // classification MqttService reuses for its "level" sensor - not the
    // decayed/display level, which is a display-smoothing concern.
    web_service.accumulateHourlyStat(led_controller.getLevelForDb(level_dB, config));

    // Sustained-threshold Babyphone alarm detector (no-op unless
    // display_mode == 2) - same tick, same raw dB input as the call above.
    web_service.updateBabyphoneState(level_dB, config);
  }

  // A real delay, not just yield(): the microphone delivers one block every
  // ~125ms, so polling at 200Hz is already ~25x oversampled. Spinning this
  // task as fast as the scheduler allows only burned CPU (and power) on
  // re-reading the same values.
  delay(5);
}

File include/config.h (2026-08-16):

#ifndef CONFIG_H
#define CONFIG_H

#include <cmath>
#include <Arduino.h>

// On native-USB-CDC boards (no USB-UART bridge chip, e.g. the ESP32-S3-Zero),
// the stock log_e/log_i/log_w/log_d macros route through ets_printf to UART0
// (physically unconnected here), NOT to the Serial/USB-CDC console - so they
// never show up in a USB serial monitor regardless of Core Debug Level.
// Redefine them to go straight to Serial, which does reach the USB-CDC host.
#undef log_e
#undef log_w
#undef log_i
#undef log_d
#define DBG_LOG(L, fmt, ...) Serial.printf("[" L "][%s:%d] " fmt "\r\n", __FILE__, __LINE__, ##__VA_ARGS__)
#define log_e(fmt, ...) DBG_LOG("E", fmt, ##__VA_ARGS__)
#define log_w(fmt, ...) DBG_LOG("W", fmt, ##__VA_ARGS__)
#define log_i(fmt, ...) DBG_LOG("I", fmt, ##__VA_ARGS__)
#define log_d(fmt, ...) DBG_LOG("D", fmt, ##__VA_ARGS__)

//
// NOISE LEVEL ENUM
//
enum NoiseLevel {
  NORMAL = 0,    // Green - below green switchover
  WARNING = 1,   // Yellow - between green and yellow switchover
  ALERT = 2      // Red - above yellow switchover
};

//
// PIN CONFIGURATION - ESP32 noiselight
//
#define DATA_PIN 1               // WS2812 LED strip (7 LEDs)
#define I2S_LR 3                // I2S L/R Select - GREEN wire (set HIGH=RIGHT channel)
#define I2S_WS 4                // I2S Word Select (L/R Clock) - BLUE wire
#define I2S_SCK 5                // I2S Serial Clock (BCLK) - WHITE wire
#define I2S_SD 2                // I2S Serial Data - YELLOW wire
#define I2S_PORT I2S_NUM_0      // Use I2S peripheral 0
#define BUTTON_PIN 6             // Mode button, wired to GND, uses internal pull-up (active LOW)

//
// BUTTON TIMING
//
#define BUTTON_DEBOUNCE_MS 30              // Ignore raw level changes faster than this
#define BUTTON_LONG_PRESS_MS 600           // Held longer than this = long press (brightness ramp) instead of short press (mode switch)
#define BUTTON_RAMP_INTERVAL_MS 30         // Time between brightness steps while held
#define BUTTON_RAMP_STEP 4                 // Brightness change (0-255) per ramp step

//
// LED CONFIGURATION
//
#define NUM_LEDS 7               // 7 WS2812 pixels
#define LED_BRIGHTNESS 25       // 0-255
#define DISPLAY_MODE 1          // 0=TRAFFIC_LIGHT, 1=VU_METER, 2=BABYPHONE, 3=SOLID_COLOR

//
// NOISE THRESHOLDS
// Grounded in WHO "Guidelines for Community Noise" (1999), Table 4.1: 50 dB LAeq is
// the moderate-annoyance guideline value for outdoor/living areas, 65 dB LAeq is the
// point past which normal conversation requires a raised voice and annoyance turns
// serious. See README "Scientific Basis" section for the full source list.
//
#define DB_FLOOR 37.0           // Noise floor baseline (~37dB)
#define DB_NORMAL_SWITCHOVER 50.0   // Below: NORMAL, Above: WARNING
#define DB_WARNING_SWITCHOVER 65.0  // Below: WARNING, Above: ALERT

//
// SOLID COLOR MODE (display_mode == 3): one user-picked color, shown either
// static or animated (blink / breathe / chase around the strip).
//
#define SOLID_COLOR 0x3B82F6     // default: a calm blue
#define SOLID_EFFECT 0           // 0=fest, 1=blinken, 2=faden, 3=lauflicht
#define SOLID_SPEED_MS 1500      // effect period: blink cycle / breathe cycle / one lap of the strip

//
// BABYPHONE MODE
//
#define BABYPHONE_TRIGGER_DB 65.0        // dB threshold that must be exceeded sustained
#define BABYPHONE_SUSTAIN_MS 5000        // how long above threshold before the alarm fires
#define BABYPHONE_CLEAR_MS 3000          // how long below threshold before the alarm clears
#define BABYPHONE_NIGHT_COLOR 0xFF3C00   // very warm amber/candlelight (almost no blue)
#define BABYPHONE_NIGHT_BRIGHTNESS 15    // 0-255, dimmed base brightness

//
// MICROPHONE CONFIGURATION
//
#define SAMPLE_RATE 48000       // Hz
#define SAMPLE_BITS 32          // bits
#define SAMPLE_T int32_t
// MEASUREMENT WINDOW: 6000 samples = 125ms. One dB value is produced per
// window. 125ms is not arbitrary - it is the "FAST" time weighting defined by
// IEC 61672, which is what every sound level meter (including the phone app
// MIC_REF_DB was calibrated against) uses. Changing it would invalidate that
// calibration and, because smoothLevel()'s alpha is applied once per window,
// would silently halve or double the display's effective time constant.
#define SAMPLES_SHORT (SAMPLE_RATE / 8)
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

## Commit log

2026-08-12 fix: avoid strict-aliasing violation in I2S sample conversion
    i2s_read() wrote raw int32 samples directly into the float `samples[]`
    buffer, then reinterpreted it as int32_t* to convert in place. Reading
    through a differently-typed pointer to the same storage is undefined
    behavior under C++'s strict aliasing rules and could be miscompiled
    under aggressive optimization. Use a dedicated int32_t buffer for the
    raw I2S read and convert explicitly into `samples[]`.
2026-08-12 fix: actually apply the A-weighting filter to audio samples
    microphone.cpp defined the INMP441 equalizer and A-weighting IIR
    filters plus a full SOS_IIR_Filter_Cpp implementation, but never
    invoked them - sum_sqr_weighted was just a copy of the raw squared
    sum. The device was measuring unweighted RMS instead of the dBA level
    the README describes. Wire up SOS_IIR_Filter_Cpp instances as members
    of Microphone and run each audio block through the equalizer then the
    A-weighting filter before computing sum_sqr_weighted.
    Also removes the free apply_sos_iir_filter() function in
    sos-iir-filter.h, which was unused and buggy on its own (a function-
    local `static float w[6][2]` state array shared acro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
2026-08-12 fix: project fails to build - unknown board ID and partition table
    platformio.ini referenced board = esp32-s3-devkitc1-n4r2, which does
    not exist in the espressif32 platform's board registry (confirmed
    against both the pinned 2022.12.0 and current 6.13.0 releases) -
    `pio run` fails immediately with UnknownBoard before compiling
    anything. Added a project-local board definition
    (boards/esp32-s3-devkitc1-n4r2.json, auto-discovered by PlatformIO)
    matching the actual hardware noted in pins.txt: ESP32-S3, 4 MB flash,
    2 MB PSRAM (N4R2), based on Espressif's official DevKitC-1 board
    definition with the flash/PSRAM fields adjusted to match Adafruit's
    N4R2 variant, the closest official match for that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
2026-08-12 fix: audio reader task could block indefinitely on a stalled consumer
    getLevel() only ever pulls one AudioSample per call (non-blocking),
    so if the main loop is ever slow (e.g. a Preferences/NVS flash write
    in the web task) more than a handful of ~125ms audio blocks, the old
    8-slot queue fills up and xQueueSend(..., portMAX_DELAY) blocks the
    I2S reader task forever, stalling audio capture until something reads
    from the queue.
    Since only the latest block is ever wanted anyway, switch to a
    length-1 mailbox queue with xQueueOverwrite(), which never blocks and
    always keeps the most recent sample. Also drops a redundant
    self-assignment (`::samples_queue = samples_queue`) left over from an
    earlie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
2026-08-12 feat: log a warning on microphone overload/clipping
    MIC_OVERLOAD_DB was defined in config.h but never referenced anywhere
    - there was no way to tell from the logs whether the mic was clipping.
    Compute the dB level from the raw (unfiltered) sum_sqr_SPL each block
    and log a throttled warning once it reaches MIC_OVERLOAD_DB.
2026-08-12 chore: remove unused SAMPLES_LEQ, correct LEQ_PERIOD
    SAMPLES_LEQ and the 0.15s LEQ_PERIOD implied a proper LEQ window
    accumulated across multiple I2S blocks, but no such accumulation
    exists anywhere - the actual measurement window is SAMPLES_SHORT
    (~125ms) directly. Removed the unused constant and corrected
    LEQ_PERIOD to reflect what's actually measured.
    [config.h]
2026-08-12 fix: LED decay logic compared enum to a color byte, not the real level
    displayTrafficLight() tried to recover the "previous noise level" by
    reading (last_color >> 16) & 0xFF - the red channel of whatever RGB
    color happened to be displayed - and comparing that byte (0-255)
    against a NoiseLevel enum (0-2). This is only coincidentally sane for
    the default colors (green=0x00FF00, red=0xFF0000); as soon as a user
    picks custom colors in the web UI (e.g. a green with a nonzero red
    channel), the decay hold either never engages or always engages
    regardless of the actual level.
    Track the last displayed NoiseLevel directly as a member instead of
    reverse-engineering it from a color. Split the switchove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
    [led.cpp]
2026-08-12 refactor: remove no-op LED FreeRTOS task
    ledTaskHandler() did nothing but vTaskDelay(50ms) in a loop - the
    comment even says "LED updates are now driven from main loop". The
    task, its wrapper, and the 4KB stack backing it were pure overhead.
    LED updates already happen exclusively via handleLevel(), called
    directly from main.cpp's loop(); removed startTask()/
    ledTaskWrapper()/ledTaskHandler() and the task_handle member along
    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
2026-08-12 fix: guard shared Config against a cross-core data race
    web_service.config was written from the web task (core 0, in
    handleApiSet) and read directly from the main loop (core 1, in
    loop()) with no synchronization - a classic data race on a POD
    struct, risking a reader observing a partially-updated config.
    Added a portMUX_TYPE spinlock and a getConfigSnapshot() accessor that
    copies config under the lock. handleApiSet() now parses the incoming
    JSON into a local Config (starting from a snapshot) and only takes
    the lock for the final assignment back, so the critical section stays
    short and never spans string parsing/heap allocation or logging.
    main.cpp's loop() now reads via getConfigSnapshot()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
    [main.cpp]
2026-08-12 fix: clamp/validate parsed config values in handleApiSet
    The hand-rolled JSON parser assigned parsed values straight into the
    Config struct with no bounds checking. Most notably, led_brightness
    is a uint8_t but was assigned an unclamped int - a negative value
    from a malformed or malicious request body would silently wrap
    instead of being rejected or clamped. dB thresholds, decay/response
    timings, and display_mode had no bounds either.
    Clamp every parsed field to the same ranges the web UI's sliders
    already allow (e.g. brightness 0-255, decay 0-3000ms, response
    0-500ms, dB thresholds 0-120). std::clamp isn't available in this
    toolchain's libstdc++, so added a small local clampValue() helper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
2026-08-12 fix: address findings from final code-review pass
    - Guard current_dB/last_dB_update with their own spinlock (dB_mux),
    same cross-core race as config: written from the main loop (core 1,
    updateLevel) and read from the web task (core 0, handleApiStatus),
    which could observe a torn 8-byte double on this 32-bit CPU.
    - Tighten handleApiSet()'s dB threshold clamps to match the web UI's
    actual slider ranges (floor 20-60, normal 30-70, warning 40-85)
    instead of a uniform 0-120, which the code comment already claimed
    but didn't implement.
    - Replace the custom clampValue() template with Arduino's built-in
    constrain() macro - same behavior, no reason to duplicate logic the
    framework a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
    [config.h]
2026-08-12 refactor: migrate handleApiGet/handleApiSet from hand-rolled to ArduinoJson
    The indexOf/substring JSON parsing in web.cpp was already fragile at 10
    fields (see the clamp fix in the previous branch's commit history). The
    home-integration work ahead adds WiFi, MQTT, and export/import fields on
    top of that, which would make the hand-rolled parser unmaintainable.
    Adds bblanchon/ArduinoJson@^6 and factors the config<->JSON mapping into
    two static helpers (configToJson/applyJsonToConfig) so the upcoming
    export/import endpoints can reuse the same clamping logic instead of
    duplicating it.
    Uses DynamicJsonDocument (ArduinoJson v6 API - the resolved dependency is
    6.21.x) rather than the v7-style bar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
2026-08-12 feat: add WiFi STA+AP fallback and mDNS via new NetworkService
    The device only ran as an isolated AP before, which doesn't work for
    always-on home use (no internet, has to be re-flashed over USB for every
    change). Adds a NetworkService (same singleton + init() pattern as
    WebService/LEDController) that tries to join a configured WiFi network on
    boot, waits up to 15s, and falls back to the existing AP mode
    (NoiseLight/12345678) if no SSID is set or the connect times out - so
    first-time setup keeps working unchanged. ESPmDNS publishes the device as
    noiselight.local in both modes.
    NetworkSettings (SSID/password, plus MQTT broker fields for the later MQTT
    phase) is deliberately kept out of the C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
    [main.cpp]
2026-08-12 feat: add ArduinoOTA support once WiFi STA is connected
    USB-only reflashing doesn't scale for always-on home use. NetworkService
    now starts ArduinoOTA right after a successful STA connect (both at boot
    and after a settings change via applySettings()) - it stays off while on
    the AP fallback, since espota targets noiselight.local which only
    resolves usefully once the device is actually on the home network.
    ArduinoOTA.handle() is pumped from the existing 50ms web task loop
    (WebService::webTaskHandler(), alongside server->handleClient()) rather
    than a new task, same as the plan calls for.
    Adds a second platformio.ini environment
    (esp32-s3-devkitc1-n4r2-ota, upload_protocol=espota,
    upload_port=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
    [config.h]
2026-08-12 feat: add MQTT + Home Assistant auto-discovery
    Adds a new MqttService (knolleary/PubSubClient@^2.8), same singleton
    pattern as the other services. Publishes two sensors per device under a
    shared HA "device" block:
    - noiselight-<id>/db - value_template pulls `db` out of the shared state
    topic, unit "dB", state_class "measurement" (needed for HA's long-term
    statistics / its own InfluxDB integration - this device never talks to
    InfluxDB directly, only MQTT, per the architecture decision already
    made).
    - noiselight-<id>/level - value_template pulls `level`
    (normal/warning/alert) from the same state topic, so topic count stays
    low.
    Device id is `noiselight-<last 6 hex of MAC>`. Stat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
    [main.cpp]
2026-08-12 feat: add config export/import (GET/POST /api/config/export|import)
    For always-on home use it's useful to back up or clone settings without
    re-clicking through every slider. Export bundles `config` (reuses
    WebService::configToJson(), same fields as /api/config) and `network`
    (WiFi/MQTT settings, including credentials) into one JSON file, download
    triggered client-side via a Blob + synthetic <a download>.
    Import reuses applyJsonToConfig() for the config half - same clamping as
    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
2026-08-12 feat: suggest a noise floor baseline from a boot-time warmup sample
    Manually finding a good db_floor means standing in the room, watching the
    live value, and moving the slider - annoying to redo after every
    reinstall/relocation. setup() now samples microphone.getLevel() every
    200ms for 4s right after microphone.init() and averages it.
    The average is deliberately NOT written into config.db_floor
    automatically - that would silently override a saved user setting on
    every reboot. Instead it's exposed as `suggested_floor` on the existing
    /api/status endpoint (only when a suggestion exists, i.e. suggested_floor
    > 0) and shown next to the Floor Level slider as a one-click "apply?"
    hint that reuses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
    [main.cpp]
2026-08-12 feat: add a 5-minute history graph to the web UI
    Adds a 300-entry ring buffer (HISTORY_SIZE, 1 sample/sec = 5 min) to
    WebService. updateLevel() downsamples into it using the same millis()
    timestamp it already computes for last_dB_update, gated on a 1000ms gap
    since the last sample. A new GET /api/history returns the buffer as an
    oldest-to-newest JSON array; the web UI polls it every 5s (separate from
    the existing 200ms live-value polling) and renders a plain <canvas> line
    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
2026-08-12 fix: address code-review findings on the home-integration branch
    - Factor the duplicated WiFi/MQTT JSON-merge logic in handleNetworkSet()
    and handleConfigImport() into one shared
    WebService::applyJsonToNetworkSettings() helper (mirrors the existing
    configToJson()/applyJsonToConfig() pattern for Config). The two copies
    had already drifted: handleNetworkSet() guarded password fields with
    strlen()>0 to avoid clobbering a saved credential on a blank field,
    handleConfigImport() didn't. The shared helper takes an
    allow_empty_password flag so each caller keeps its correct behavior
    (false for the UI's incremental save, true for import, where an
    exported file's fields - including a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
    [config.h]
2026-08-12 feat: add hourly noise-level time distribution (Tagesstatistik)
    Adds NTP time sync (manual UTC-offset setting, no timezone database) and
    a 24-hour-bucket "today" view of time spent in each color state, served
    from /api/hourly and rendered as a stacked bar chart in the web UI. Auto-
    resets at local midnight, with a manual reset button too. Follows the
    existing Config/NetworkSettings NVS persistence and portMUX_TYPE locking
    patterns used elsewhere in WebService/NetworkService.
    [main.cpp]
2026-08-12 feat: bake WiFi credentials from a gitignored .env into first-boot NVS default
    Lets a freshly flashed device join a known home network directly,
    without needing to connect to its AP fallback first (useful when the
    AP isn't visible/reachable from the phone doing setup). NVS-stored
    settings saved via the web UI always take precedence once set.
2026-08-12 fix: use a POSIX TZ string instead of a fixed UTC offset for Tagesstatistik hours
    A plain UTC-offset-in-minutes can't represent when DST starts/ends, so
    hourly-stats buckets drifted by an hour during summer/winter time
    transitions. Switch to configTzTime() with a POSIX TZ string (e.g.
    "CET-1CEST,M3.5.0,M10.5.0/3" for Europe/Berlin, now the default),
    which encodes the DST rule itself and lets localtime_r() apply it
    automatically year-round.
2026-08-13 Add 3D printing models for deciLight enclosure
    Includes Fusion 360 source and per-part 3MF exports for the main body, feet, lens, and reflector.
    [deciLight-feet.3mf, deciLight-lens.3mf, deciLight-main.3mf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]
2026-08-13 Add README with print settings for 3D models
    Documents the Bambu Studio slicer settings embedded in each .3mf (material, layer height, temps, infill) so parts can be reprinted without re-deriving them from the project files.
2026-08-14 fix: rewire for Waveshare ESP32-S3-Zero, fix PSRAM boot instability and dead mic
    - Update pin assignments for the actual soldered header side: LED data
    GPIO1 (7 LEDs), I2S LR/WS/SCK/SD on GPIO3/4/5/2.
    - Remove the custom board's forced BOARD_HAS_PSRAM define. This board's
    Arduino profile ships with PSRAM disabled by default; forcing it on
    caused intermittent USB-CDC dropouts and boot instability that looked
    like a bad board/cable/etc. before being traced to this.
    - Rename network.h/network.cpp -> net_manager.h/net_manager.cpp. On
    case-insensitive filesystems (APFS), our own network.h was shadowing
    the ESP32 core's Network.h (quoted #include falls through to the
    sketch dir, whic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
    [config.h, main.cpp]
2026-08-14 fix: move I2S mic pins off strapping-adjacent GPIOs on ESP32-S3-Zero
    GPIO4-7 conflicted with onboard peripherals on the Waveshare S3-Zero,
    causing boot instability and a dead mic. Move I2S_LR/WS/SCK/SD to
    GPIO12/11/10/13.
    [config.h]
2026-08-14 docs: fix LED count and note HA integration is untested
    README still said 12 LEDs from the pre-S3-Zero hardware; the current
    build uses 7. Also flag that MQTT/Home Assistant discovery hasn't
    been verified end-to-end against a live HA instance yet, unlike
    everything else in this README.
2026-08-14 fix: correct sign in IIR direct-form-II recursion, recalibrate mic
    The SOS filter's Direct Form II state update used w(n) = x(n) - a1*w(n-1)
    - a2*w(n-2), but this filter's coefficients (adapted from the upstream
    esp32-i2s-slm reference) only have stable poles with addition. Subtracting
    flipped them outside the unit circle, so the filter diverged to Inf/NaN
    within a single block.
    Also recalibrate MIC_REF_DB from 80.0 to 67.0 against a phone SPL meter
    (was reading 13dB high), and add periodic debug logging of the raw/filtered
    sample stats to make future divergence easier to spot.
    [config.h]
2026-08-14 fix: bump WebTask stack from 4096 to 8192 bytes
    MQTT reconnect/discovery (MqttService::loop(), called synchronously
    from WebTaskHandler) runs PubSubClient::connect()'s TCP handshake
    plus JSON serialization on the same task that was already sized only
    for plain HTTP + OTA. Actually configuring a broker overflows the
    4096-byte stack and boot-loops the device (drops off WiFi ~1s after
    connecting, right after MQTT settings are saved) - reported after
    first testing MQTT against a real broker.
2026-08-15 feat: browser-based OTA update, MQTT diagnostics, and noiselight rebrand
    - Add a web UI firmware upload endpoint (/update, Update.h-based, HTTP
    Basic Auth) so a .bin can be flashed directly from a browser tab, no
    PlatformIO/Arduino IDE required
    - Add FIRMWARE_VERSION with a WebUI footer + MQTT debug topic (uptime,
    free heap, WiFi RSSI, IP, last reset reason) as Home Assistant
    diagnostic entities, plus a "last alert" timestamp sensor
    - Auto-generate firmware/<version>.bin on every build via a new
    copy_firmware_bin.py post-build hook
    - Fix OTA never actually taking effect: pin platformio.ini to the
    pioarduino espressif32 fork (Arduino-ESP32 3.3.11 / ESP-IDF 5.5.5) to
    match the Ar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
    [config.h, main.cpp]
2026-08-15 feat: redesign WebUI as bilingual status-first drawer layout
    Replaces the single flat config page with a status block (live dB
    meter, 5-min history as an SVG polyline, today's hourly stacked
    bars) always visible above three collapsible <details> groups
    (Licht/Netzwerk/Gerät), each showing its current value inline when
    closed. Adds an EN/DE toggle (navigator.language-guessed, persisted
    in localStorage) and a two-column layout above 860px. All existing
    HTTP endpoints/JSON contracts are unchanged - only html_ui was
    rewritten.
    Bumps FIRMWARE_VERSION to 1.3.0 for this UI/i18n change.
    Claude-Session: https://claude.ai/code/session_01Hqabqn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
    [config.h]
2026-08-15 fix: stop rebuilding meter gradient/hint on every 200ms status poll
    renderLive() ran 5x/sec and rebuilt a full CSS gradient string plus an
    innerHTML+addEventListener pair every tick, on top of ~20 repeated
    getElementById() lookups. Cheap on desktop, but heavy enough on iOS Safari
    to starve the main thread and delay native <details> drawer toggles by
    several seconds. Cache el() lookups and only rebuild the gradient/hint when
    their underlying values actually change.
    Claude-Session: https://claude.ai/code/session_01HqabqnoB1nPbDKZfiVqixy
    [config.h]
2026-08-15 feat: live listening as a first-class control, split credentials, ~47KB heap
    Live listening moves out of the Babyphone drawer under "Licht" into its own
    card in the status rail, directly under the level readout. It was never a
    light setting, and it is the one control you reach for in a hurry. The
    display_mode == 2 gate is gone too: AudioStreamService never checked the mode
    either, so hiding it was a UI-only restriction.
    It now has its own credential, LIVE_PASSWORD ("changeme-live"), separate from
    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
2026-08-15 feat: rework live-listen audio chain for natural-sounding speech
    The live stream was peak-normalising every 62.5ms block on its own with a
    72dB ceiling and an instant release, so room tone was pushed to full scale
    in every pause and yanked back down on every sound - the "empty hall"
    pumping. Decimation was a 3-tap boxcar that folded the whole 8-16kHz band
    back into the audible range, and a `gain < 1.0f -> 1.0f` clamp hard-clipped
    anything above ~71dB SPL.
    Replaced with: a 63-tap Hamming-windowed sinc anti-alias filter (6.7kHz
    cutoff - flat to 5.4kHz so consonants survive, stopband under the 8kHz
    Nyquist), an 80Hz rumble highpass, and an RMS-envelope AGC with instant
    attack, ~2s release and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
    [config.h]
2026-08-15 feat: raise live-listen stream from 16kHz to 24kHz
    8kHz of bandwidth was the binding limit on how open speech could sound -
    no anti-alias filter, however good, gets past its own output Nyquist.
    Decimate by 2 instead of 3 for 12kHz of bandwidth, which covers sibilance
    properly. Costs 50% more WiFi (48KB/s) and 16KB more ring buffer, neither
    of which is scarce here.
    Both filters now derive their coefficients from AUDIO_STREAM_SAMPLE_RATE
    in streamFirInit() rather than carrying hand-computed literals: the FIR
    cutoff from the output Nyquist minus half the Hamming transition width,
    the highpass from its corner frequency. Before this the 6.7kHz cutoff and
    the 0.969 highpass coefficient were both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
    [config.h]
2026-08-15 fix: display mode as its own card, applied on click
    The status card at the top renders from lastConfig - what the DEVICE
    reports - but fetchConfig() only runs at page load, so a mode picked in
    the Licht drawer stayed invisible up there until a reload. It was only
    sent at all when "Lichteinstellungen speichern" was pressed, so the two
    could disagree indefinitely.
    Moves the mode out of Licht into its own "Betriebsart" card and applies
    it on click: POST, then fetchConfig() to re-sync from the device, with
    the top tile updated optimistically so it reacts on the same frame as the
    radio button. display_mode is dropped from the Licht save payload - one
    owner, so a stale radio state can't overwrite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
2026-08-15 feat: 24-hour timestamps and an inline SVG favicon
    toLocaleTimeString() with no arguments follows the BROWSER's locale, so
    the same device rendered "23:10:45" for one household member and
    "11:10:45 PM" for another. The rest of the UI is 24-hour throughout - the
    hourly chart's 00-23 axis, "seit 00:00 Uhr" - so the locale default was
    the odd one out. Replaced at all three call sites with a fmtTime() helper
    that pads by hand.
    The favicon is a data-URI SVG in <head> rather than a /favicon.ico route:
    no extra handler on the single WebTask, no binary in flash, and the
    browser never issues the request at all. Three rising bars in the UI's own
    --quiet/--warn/--alert colours, which stays legible at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
2026-08-16 feat: solid color display mode, GPIO 6 mode button, and mic-button README docs
    Adds a 4th display mode (solid color, static or blink/breathe/chase) and
    a physical mode button on GPIO 6: short press cycles display modes, long
    press ramps LED brightness with ping-pong at 0/255. MQTT state string
    gains "solid_color". README documents wiring and button gestures in DE/EN.
    [config.h, led.cpp, main.cpp]
2026-08-16 docs: refresh web UI screenshots to match current interface
    The old doc/webUI-live.png and doc/webUI.jpeg screenshots showed a
    completely different, long-superseded UI ("Noise Light" title, gradient
    level bar). Captured fresh screenshots of the current dashboard
    (live/operating-mode view) and expanded light settings via
    claude-in-chrome, and updated the README captions accordingly.
2026-08-16 docs: update README captions and finish screenshot content swap
    Follow-up to 86ea49c: the rename went through but the actual new
    image content and README caption text hadn't been staged yet.
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2026-08-16 docs: cite WHO/NIOSH/OSHA sources for green/yellow/red thresholds
    Grounds the existing 50/65 dB defaults in WHO Guidelines for Community
    Noise (1999) and adds occupational limits (NIOSH/OSHA) as context for
    why RED is a comfort threshold, not a hearing-damage warning.
    [config.h]
